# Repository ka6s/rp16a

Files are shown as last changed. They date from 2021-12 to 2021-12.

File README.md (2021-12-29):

# rp16a
This is version 1.3 of the rp16a Red Pitaya Shield.  This is an enhancment over the rp_adapter in several ways.  The design adds 10db and 20db attenuation. It has interfaces for both Alex filtering and 4 bit bus control for OTHER external filters.  It provides control for a 3 antenna switch.   The design uses a single 12V supply and mounts the Red Pitaya underneath the shield. 

Also contained within this repository are the following:
sdr-transceiver-hpsdr.c - custom version of Pavel's code to use with this radio.  
cc - compiler command to compile the above.
RP_i2c_to_SPI_v2.tar.gz - PSoC Creator 4.4 tar ball for the on-board PSOC that provides antenna control and translation for Alex.

If you aren't going to use Alex -and only 1 antenna - then you don't need any of these files.

Steve KA6S

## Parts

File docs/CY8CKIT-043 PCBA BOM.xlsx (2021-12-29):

TITLE |  | CY8CKIT-043 PSoC 4 M-Series Prototyping Kit
PCA # |  | 121-60220-01 | REV 04
SCH # |  | 630-60252-01 | REV 04
DATE |  | 2015-06-24
Item | Qty | Reference | Value | Description | Manufacturer | Mfr Part Number | Sub Allowed | ROHS | UL Certified
1 | 1 | 600-60250-01 REV04 | - | PCB, 116.51 mm x 24.13 mm, High Tg, ENIG finish, 2 layer, Color = RED, Silk = WHITE | Cypress Semiconductor | 600-60250-01 | N/A | Yes | Yes
2 | 14 | C1,C4,C5,C6,C8,C11,C14,C18,C19,C20,C22,C29,C33,C34 | 0.1 uFd | CAP CER 0.1UF 10V 10% X5R 0402 | TDK Corporation | C1005X5R1A104K050BA | ASK | Yes | Yes
3 | 13 | C3,C15,C16,C17,C21,C23,C24,C25,C26,C27,C28,C31,C32 | 1.0 uFd | CAP CERAMIC 1.0UF 25V X5R 0603 10% | Taiyo Yuden | TMK107BJ105KA-T | ASK | Yes | Yes
4 | 1 | C9 | 18 pF | CAP CER 18PF 50V 1% NP0 0402 | Murata Electronics | GRM1555C1H180FA01D | ASK | Yes | Yes
5 | 1 | C10 | 2200 pFd | CAP CER 2200PF 50V 5% NP0 0805 | Murata | GRM2165C1H222JA01D | ASK | Yes | Yes
6 | 1 | C12 | 36 pF | CAP CER 36PF 50V 5% NP0 0402 | Murata Electronics | GRM1555C1H360JA01D | ASK | Yes | Yes
7 | 1 | C13 | 10000 pFd | CAP CER 10000PF 50V 5% NP0 0805 | Murata | GRM2195C1H103JA01D | ASK | Yes | Yes
8 | 1 | D1 | MBR0520L | DIODE SCHOTTKY 0.5A 20V SOD-123 | Fairchild Semiconductor | MBR0520L | ASK | Yes | Yes
9 | 1 | F1 | PTC Resettable Fuse | FUSE, PTC Resettable, 0.50A, 16V, 1210, SMD | Bel Fuse Inc | 0ZCH0050FF2G | ASK | Yes | Yes
10 | 1 | LED1 | User LED BLUE | LED, BLUE, CLEAR, 0805, SMD | Lite-On Inc | LTST-C170TBKT | ASK | Yes | Yes
11 | 1 | LED2 | Power LED Amber | LED 595NM AMB DIFF 0805 SMD | Avago Technologies | HSMA-C170 | ASK | Yes | Yes
12 | 1 | LED3 | Status LED Green | LED GREEN CLEAR 0805 SMD | Chicago Miniature | CMD17-21VGC/TR8 | ASK | Yes | Yes
13 | 3 | L1,L2,L3 | 330 OHM @ 100MHz | FILTER CHIP 330 OHM 1.5A 0603 | Murata Electronics | BLM18SG331TN1D | ASK | Yes | Yes
14 | 2 | R2,R3 | 15K | RES SMD 15K OHM 5% 1/10W 0402 | Panasonic - ECG | ERJ-2GEJ153X | ASK | Yes | Yes
15 | 2 | R4,R5 | 22E | RES SMD 22 OHM 1% 1/10W 0402 | Panasonic - ECG | ERJ-2RKF22R0X | ASK | Yes | Yes
16 | 2 | R6,R8 | 2.2K | RES 2.2K OHM 1/10W 5% 0603 SMD | Panasonic - ECG | ERJ-3GEYJ222V | ASK | Yes | Yes
17 | 2 | R7,R22 | ZERO | RES 0.0 OHM 1/8W 0805 SMD | Panasonic-ECG | ERJ-6GEY0R00V | ASK | Yes | Yes
18 | 1 | R9 | 560 ohm | RES 560 OHM 1/10W 5% 0603 SMD | Panasonic - ECG | ERJ-3GEYJ561V | ASK | Yes | Yes
19 | 2 | R10,R12 | 30K | RES SMD 30K OHM 5% 1/10W 0402 | Panasonic - ECG | ERJ-2GEJ303X | ASK | Yes | Yes
20 | 12 | R11,R13,R14,R16,R17,R18,R20,R21,R24,R26,R27,R28 | ZERO | RES 0.0 OHM 1/8W 0603 SMD | Panasonic-ECG | ERJ-3GEY0R00V | ASK | Yes | Yes
21 | 1 | R15 | 560 ohm | RES 560 OHM 1/8W 5% 0805 SMD | Panasonic - ECG | ERJ-6GEYJ561V | ASK | Yes | Yes
22 | 1 | R19 | 820 ohm | RES 820 OHM 1/8W 5% 0603 SMD | Panasonic - ECG | ERJ-3GEYJ821V | ASK | Yes | Yes
23 | 2 | SW1,SW3 | SW PUSHBUTTON | SWITCH TACTILE SPST-NO 0.05A 32V | C&K Components | KMR221GLFS | ASK | Yes | Yes
24 | 1 | U1 | PSoC 5LP | 68QFN PSoC 5LP chip for USB debug channel and USB-Serial interface | Cypress Semiconductor | CY8C5868LTI-LP039 | ASK | Yes | Yes
25 | 1 | U2 | PSoC 4200M | 68TQFP PSoC 4M | Cypress Semiconductor | CY8C4247AZI-M485 | ASK | Yes | Yes
26 | 1 | U3 | DUAL PMOS | MOSFET 2P-CH 20V 430MA SOT-563 | ON Semiconductor | NTZD3152PT1G | ASK | Yes | Yes
Label
27 | 1 | N/A | N/A | LBL, PCA Label, Vendor Code, Datecode, Serial Number 121-60220-01 Rev 04 (YYWWVVXXXXX) | Cypress Semiconductor |  | ASK | Yes | Yes
No load components
28 | 2 | C2,C30 | 0.1 uFd | CAP CER 0.1UF 10V 10% X5R 0402 | TDK Corporation | C1005X5R1A104K050BA | ASK | Yes | Yes
29 | 1 | C7 | 1.0 uFd | CAP CERAMIC 1.0UF 25V X5R 0603 10% | Taiyo Yuden | TMK107BJ105KA-T | ASK | Yes | Yes
30 | 1 | J4 | HDR 1x2 | CONN HEADR BRKWAY .100 02POS STR | TE Connectivity | 9-146280-0-02 | ASK | Yes | Yes
31 | 1 | J5 | 50MIL KEYED SMD | CONN HEADER 10 PIN 50MIL KEYED SMD | Samtec | FTSH-105-01-L-DV-K | ASK | Yes | Yes
32 | 1 | R1 | 4.7K | RES SMD 4.7K OHM 5% 1/10W 0402 | Panasonic - ECG | ERJ-2GEJ472X | ASK | Yes | Yes
33 | 1 | R25 | ZERO | RES 0.0 OHM 1/8W 0805 SMD | Panasonic - ECG | ERJ-6GEY0R00V | ASK | Yes | Yes
34 | 1 | R23 | 4.7K | RES 4.7K OHM 1/10W 5% 0603 SMD | Panasonic - ECG | ERJ-3GEYJ472V | ASK | Yes | Yes
35 | 1 | SW2 | SW PUSHBUTTON | SWITCH TACTILE SPST-NO 0.05A 32V | C&K Components | KMR221GLFS | ASK | Yes | Yes
36 | 1 | SW4 | DPDT SW | SWITCH SLIDE DPDT 200MA 12V | Copal Electronics | CL-SB-22B-02T | ASK | Yes | Yes
37 | 1 | TP5 | BLACK | TEST POINT 43 HOLE 65 PLATED BLACK | Keystone Electronics | 5001 | ASK | Yes | Yes
38 | 4 | TP1,TP2,TP3,TP4 | RED | TEST POINT 43 HOLE 65 PLATED RED | Keystone Electronics | 5000 | ASK | Yes | Yes
39 | 1 | U4 | EZ-BLE | EZ-BLE PRoC BLE Module, 10 mm X 10 mm X 1.8 mm | Cypress Semiconductor | CYBLE-022001-00 | ASK | Yes | Yes

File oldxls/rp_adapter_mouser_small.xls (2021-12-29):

Mouser Part number | Manufacturer | Mfg Part Number | Description | Location | Quantity | Price 1 | Cost/Unit/10 | Location | Price 1 | Min\Mult Order Qty | Quoted Part Number
81-GRM422X105K50L (http://www.mouser.com/ProductDetail/Murata-Electronics/GRM32RR71H105KA01L/) | Murata | GRM32RR71H105KA01L (http://www.mouser.com/ProductDetail/Murata-Electronics/GRM32RR71H105KA01L/) | 1uF | C53,C55,C57,C54,C40 | 7 | 0.32 | 0.17 |  | $0.17 | 1\1 | 81-GRM422X105K50L
81-GRM422R106K16L (http://www.mouser.com/ProductDetail/Murata-Electronics/GRM32DR61C106KA01L/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) | Murata | GRM32DR61C106KA01L (http://www.mouser.com/ProductDetail/Murata-Electronics/GRM32DR61C106KA01L/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) | 10uF | C30,C2,C47,C49,C48,C41,C37,C42,C43 | 10 | 0.32 | 0.185 |  | $0.255 | 1\1 | 81-GRM422R106K16L
80-C1206C104K5R (http://www.mouser.com/ProductDetail/Kemet/C1206C104K5RACTU/) | Kemet | C1206C104K5RACTU (http://www.mouser.com/ProductDetail/Kemet/C1206C104K5RACTU/) | 0.1uF | C44,C50,C35,C36,C34,C33,C39,C38,C45,C51,C46,C52,C31 | 15 | 0.1 | 0.042 |  | $0.042 | 1\1 | 80-C1206C104K5R
80-C1210C107M4PACTU (http://www.mouser.com/ProductDetail/Kemet/C1210C107M4PACTU/) | Kemet | C1210C107M4PACTU (http://www.mouser.com/ProductDetail/Kemet/C1210C107M4PACTU/) | 100uF | C55,C54,C53,C40,C57,C1 | 7 | 2.46 | 0.836 |  | $2.46 | 1\1 | 80-C1210C107M4PACTU
490-PJ-002BH | Cui | PJ-002BH | BARREL_JACK | CON1 | 1 | 1.16 | 1.25 |  | $1.16 | 1\1 | 490-PJ-002BH
576-0437005.WR (http://www.mouser.com/ProductDetail/Littelfuse/0437005WR/) | Littelfuse (http://www.mouser.com/littelfuse) | 0437005.WR (http://www.mouser.com/ProductDetail/Littelfuse/0437005WR/) | FUSE | F1 | 1 | 0.92 | 0.688 |  | $0.92 | 1\1 | 576-0437005.WR
532-529801B25G | Aavid Thermalloy | 529801B02500G | HEATSINK | HS3,HS2 | 2 | 1.47 | 1.39 |  | $1.47 | 1\1 | 532-529801B25G
710-618015231221 (http://www.mouser.com/ProductDetail/Wurth-Electronics/618015231221/?qs=sGAEpiMZZMt93J8DTi5DC553G%252bzlR8Bc) | Wurth | 618015231221 (http://www.mouser.com/ProductDetail/Wurth-Electronics/618015231221/?qs=sGAEpiMZZMt93J8DTi5DC553G%252bzlR8Bc) | DB15 | J1 | 1 | 3.21 | 3.06 |  | $3.21 | 1\1 | 710-618015231221
523-L717SDB25P1ACH3R | Amphenol | L717SDB25P1ACH3R (http://www.mouser.com/ProductDetail/Amphenol-Commercial-Products/L717SDB25P1ACH3R/) | DB25 | J2 | 1 | 2.38 | 2.28 |  | $2.38 | 1\1 | 523-L717SDB25P1ACH3R
712-CONSMA002 (http://www.mouser.com/ProductDetail/Linx-Technologies/CONSMA002/?qs=K5ta8V%252bWhtYroTuiMsq2AA%3D%3D) | Linx Tech | CONSMA002 (http://www.mouser.com/ProductDetail/Linx-Technologies/CONSMA002/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) | SMA | J4,J3,J5 | 3 | 3.31 | 3.03 |  | $3.31 | 1\1 | 712-CONSMA002
490-SJ1-3533N (http://www.mouser.com/ProductDetail/CUI/SJ1-3533N/) | Cui | SJ1-3533N | JACK_2P | J11,J10,J9,J8,J6 | 5 | 1.6 | 1.24 |  | $1.60 | 1\1 | 490-SJ1-3533N
653-G6J-2P-Y-DC12 (http://www.mouser.com/ProductDetail/Omron-Electronics/G6J-2P-Y-DC12/) | Omron | G6J-2P-Y-DC12 | RELAY_RF | K2,K1 | 2 | 4.29 | 4.03 |  | $4.29 | 1\1 | 653-G6J-2P-Y-DC12
81-NFZ32BW621HN10L | Murata | NFZ32BW621HN10L | FB | L5,L4,L6,L3,L7 | 6 | 0.41 | 0.269 |  | $0.269 | 1\1 | 81-NFZ32BW621HN10L
563-BC-32678 | Bud Industries | BC-32678 | CONN_02X13 | P2,P1 | 2 | 2 | 1.8 |  | $2.00 | 1\1 | 563-BC-32678
652-CR1206FX-75R0ELF (http://www.mouser.com/ProductDetail/Bourns/CR1206-FX-75R0ELF/) | Bourns | CR1206-FX-75R0ELF (http://www.mouser.com/ProductDetail/Bourns/CR1206-FX-75R0ELF/) | 75 | R13 | 5 | 0.1 | 0.042 |  | $0.10 | 1\1 | 652-CR1206FX-75R0ELF
667-ERJ-8RQF5R1V (http://www.mouser.com/ProductDetail/Panasonic/ERJ-8RQF5R1V/) | Panasonic | ERJ-8RQF5R1V (http://www.mouser.com/ProductDetail/Panasonic/ERJ-8RQF5R1V/) | 5R1 | R22,R21 | 5 | 0.56 | 0.22 |  | $0.56 | 1\1 | 667-ERJ-8RQF5R1V
71-CP00102R200JE663 | Vishay | CP00102R200JE663 | 2R2 | R24,R23 | 2 | 0.67 | 0.495 |  | $4.29 | 1\1 | 653-G6J-2P-Y-DC12
667-ERJ-8GEYJ472V (http://www.mouser.com/ProductDetail/Panasonic/ERJ-8GEYJ472V/) | Panasonic | ERJ-8GEYJ472V (http://www.mouser.com/ProductDetail/Panasonic/ERJ-8GEYJ472V/) | 4.7K | R27,R25,R26 | 5 | 0.1 |  |  | $0.022 | 1\1 | 667-ERJ-8GEYJ472V
512-KA278R12CTU (http://www.mouser.com/ProductDetail/Fairchild-Semiconductor/KA278R12CTU/) | Fairchild | KA278R12CTU (http://www.mouser.com/ProductDetail/Fairchild-Semiconductor/KA278R12CTU/) | KA278R12 | U10 | 1 | 0.99 | 0.848 |  | $0.99 | 1\1 | 512-KA278R12CTU
879-1336G1 (http://www.mouser.com/ProductDetail/Anderson-Power-Products/1336G1/?qs=sGAEpiMZZMuP%2FQeRSdvksJ%2FdnJShAKpx) | Anderson Power Products (http://www.mouser.com/Anderson-Power-Products/) | 1336G1 (http://www.mouser.com/ProductDetail/Anderson-Power-Products/1336G1/?qs=sGAEpiMZZMuP%2FQeRSdvksJ%2FdnJShAKpx) | PwrPole | U11 | 2 | 0.54 |  |  | $0.54 | 1\1 | 879-1336G1
879-1327G6 (http://www.mouser.com/ProductDetail/Anderson-Power-Products/1327G6/?qs=sGAEpiMZZMuP%2FQeRSdvksFwvD3ebCz4Y) | Anderson Power Products (http://www.mouser.com/Anderson-Power-Products/) | 1327G6 | 1327G6 (http://www.mouser.com/ProductDetail/Anderson-Power-Products/1327G6/?qs=sGAEpiMZZMuP%2FQeRSdvksFwvD3ebCz4Y) | U12,U11 | 2 |  |  |  | $0.48 | 1\1 | 879-1327G6
879-1327 (http://www.mouser.com/ProductDetail/Anderson-Power-Products/1327/?qs=sGAEpiMZZMuP%2FQeRSdvksHAvir4742Xo) | Anderson Power Products (http://www.mouser.com/Anderson-Power-Products/) | 1327 | PwrPole Shroud Red | U12,U11 | 2 |  |  |  | $0.50 | 1\1 | 879-1327
879-1335G1 (http://www.mouser.com/ProductDetail/Anderson-Power-Products/1335G1/?qs=sGAEpiMZZMuP%2FQeRSdvksBiQHnjEfqU3) | Anderson Power Products (http://www.mouser.com/Anderson-Power-Products/) | 1335G1 (http://www.mouser.com/ProductDetail/Anderson-Power-Products/1335G1/?qs=sGAEpiMZZMuP%2FQeRSdvksBiQHnjEfqU3) | Powe Pole Vert | U12 | 2 |  |  |  |  | 1\1 | 879-1335G1
700-MAX2611EUS+T (http://www.mouser.com/ProductDetail/Maxim-Integrated/MAX2611EUS+T/?qs=GxOUx7aO6nzhsdyrBwYTYA%3D%3D) | Maxim | MAX2611EUS+T | MAX2611 | U6 | 1 | 1.78 | 1.68 |  | $1.78 | 1\1 | 700-MAX2611EUS+T
595-OPA2674ID (http://www.mouser.com/ProductDetail/Texas-Instruments/OPA2674ID/?qs=7nS3%252bbEUL6ta%252bQbwv%2FJuYg%3D%3D) | TI | OPA2674ID (http://www.mouser.com/ProductDetail/Texas-Instruments/OPA2674ID/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) | OPA26741C | U7 | 1 | 4.14 | 3.72 |  | $4.14 | 1\1 | 595-OPA2674ID
512-KA278R05CTU | Fairchild | KA278R05CTU | KA278R05 | U8,U9 | 2 | 0.98 | 0.836 |  | $0.98 | 1\1 | 512-KA278R05CTU
571-5-1634506-1 | TE Connectivity (http://www.mouser.com/TE-Connectivity/) | 5-1634506-1 | BNC_VERTICAL | P8,P10,P14,P9,P15 | 5 | 1.36
511-ULN2001A | STMicro | ULN2001A | ULN2004A | U1,U2 | 2 | 0.47
279-CBT50J100R (http://www.mouser.com/ProductDetail/TE-Connectivity-Neohm/CBT50J100R/) | TE Connectivity | CBT25J100R (http://www.mouser.com/ProductDetail/TE-Connectivity-Neohm/CBT25J100R/) | 100 | R15,R16 | 2
603-MFR-25FRF521K (http://www.mouser.com/ProductDetail/Yageo/MFR-25FRF52-1K/) | Yageo | MFR-25FRF52-1K (http://www.mouser.com/ProductDetail/Yageo/MFR-25FRF52-1K/) | 1K | R18,R17,R19,R20 | 4
 |  |  | CONN_01X29 | P3,P4 | 2

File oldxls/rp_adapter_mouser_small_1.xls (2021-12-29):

Mouser Part number | Manufacturer | Mfg Part Number | Description | Location | Quantity | Price 1 | Cost/Unit/10 | Location | Price 1 | Min\Mult Order Qty | Quoted Part Number
81-GRM422X105K50L (http://www.mouser.com/ProductDetail/Murata-Electronics/GRM32RR71H105KA01L/) | Murata | GRM32RR71H105KA01L (http://www.mouser.com/ProductDetail/Murata-Electronics/GRM32RR71H105KA01L/) | 1uF | C56,C32,C25,C24,C9,C7,C5,C3,C2,C1 | 20 | 0.32 | 0.17 |  | $0.17 | 1\1 | 81-GRM422X105K50L
80-C1206C101K5R (http://www.mouser.com/ProductDetail/Kemet/C1206C101K5RACTU/) | Kemet | C1206C101K5RACTU (http://www.mouser.com/ProductDetail/Kemet/C1206C101K5RACTU/) | 100pF | C23,C22,C21,C20,C18,C17,C16,C15,C14,C13,C12,C19 | 15 | 0.1 | 0.042 |  | $0.185 | 1\1 | 80-C1206C101K5R
81-GRM422R106K16L (http://www.mouser.com/ProductDetail/Murata-Electronics/GRM32DR61C106KA01L/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) | Murata | GRM32DR61C106KA01L (http://www.mouser.com/ProductDetail/Murata-Electronics/GRM32DR61C106KA01L/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) | 10uF | C49,C48,C47,C43,C42,C41,C37,C30 | 10 | 0.32 | 0.185 |  | $0.255 | 1\1 | 81-GRM422R106K16L
80-C1206C104K5R (http://www.mouser.com/ProductDetail/Kemet/C1206C104K5RACTU/) | Kemet | C1206C104K5RACTU (http://www.mouser.com/ProductDetail/Kemet/C1206C104K5RACTU/) | 0.1uF | C52,C51,C50,C46,C45,C44,C39,C38,C36,C35,C34,C33,C31,C29,C28,C27,C26,C11,C10,C8,C6,C4 | 25 | 0.1 | 0.042 |  | $0.042 | 1\1 | 80-C1206C104K5R
80-C1210C107M4PACTU (http://www.mouser.com/ProductDetail/Kemet/C1210C107M4PACTU/) | Kemet | C1210C107M4PACTU (http://www.mouser.com/ProductDetail/Kemet/C1210C107M4PACTU/) | 100uF | C55,C54,C53,C40,C57 (1210) | 8 | 2.46 | 0.836 |  | $2.46 | 1\1 | 80-C1210C107M4PACTU
490-PJ-002BH | Cui | PJ-002BH | BARREL_JACK | CON1 | 1 | 1.16 | 1.25 |  | $1.16 | 1\1 | 490-PJ-002BH
576-0437005.WR (http://www.mouser.com/ProductDetail/Littelfuse/0437005WR/) | Littelfuse (http://www.mouser.com/littelfuse) | 0437005.WR (http://www.mouser.com/ProductDetail/Littelfuse/0437005WR/) | FUSE | F1 | 1 | 0.92 | 0.688 |  | $0.92 | 1\1 | 576-0437005.WR
532-529801B25G | Aavid Thermalloy | 529801B02500G | HEATSINK | HS3,HS2 | 2 | 1.47 | 1.39 |  | $1.47 | 1\1 | 532-529801B25G
710-618015231221 (http://www.mouser.com/ProductDetail/Wurth-Electronics/618015231221/?qs=sGAEpiMZZMt93J8DTi5DC553G%252bzlR8Bc) | Wurth | 618015231221 (http://www.mouser.com/ProductDetail/Wurth-Electronics/618015231221/?qs=sGAEpiMZZMt93J8DTi5DC553G%252bzlR8Bc) | DB15 | J1 | 1 | 3.21 | 3.06 |  | $3.21 | 1\1 | 710-618015231221
523-L717SDB25P1ACH3R | Amphenol | L717SDB25P1ACH3R (http://www.mouser.com/ProductDetail/Amphenol-Commercial-Products/L717SDB25P1ACH3R/) | DB25 | J2 | 1 | 2.38 | 2.28 |  | $2.38 | 1\1 | 523-L717SDB25P1ACH3R
712-CONSMA002 (http://www.mouser.com/ProductDetail/Linx-Technologies/CONSMA002/?qs=K5ta8V%252bWhtYroTuiMsq2AA%3D%3D) | Linx Tech | CONSMA002 (http://www.mouser.com/ProductDetail/Linx-Technologies/CONSMA002/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) | SMA | J5,J4,J3 | 3 | 3.31 | 3.03 |  | $3.31 | 1\1 | 712-CONSMA002
490-SJ1-3533N (http://www.mouser.com/ProductDetail/CUI/SJ1-3533N/) | Cui | SJ1-3533N | JACK_2P | J11,J10,J9,J8,J6 | 5 | 1.6 | 1.24 |  | $1.60 | 1\1 | 490-SJ1-3533N
653-G6J-2P-Y-DC12 (http://www.mouser.com/ProductDetail/Omron-Electronics/G6J-2P-Y-DC12/) | Omron | G6J-2P-Y-DC12 | RELAY_RF | K2,K1 | 2 | 4.29 | 4.03 |  | $4.29 | 1\1 | 653-G6J-2P-Y-DC12
81-LQH31MNR47K03L (http://www.mouser.com/ProductDetail/Murata-Electronics/LQH31MNR47K03L/) | Murata | LQH31MNR47K03L (http://www.mouser.com/ProductDetail/Murata-Electronics/LQH31MNR47K03L/) | 0.47uH | L2,L1 | 2 | 0.44 | 0.335 |  | $0.44 | 1\1 | 81-LQM31PNR47MC0L
81-NFZ32BW621HN10L | Murata | NFZ32BW621HN10L | FB | L6,L5,L4,L3,L7 | 6 | 0.41 | 0.269 |  | $0.269 | 1\1 | 81-NFZ32BW621HN10L
645-598-8270-107F (http://www.mouser.com/ProductDetail/Dialight/598-8270-107F/) | Dialight | 598-8270-107F (http://www.mouser.com/ProductDetail/Dialight/598-8270-107F/) | LED | LED_D1,LED_C1,LED_B1,LED_A1 | 4 | 0.46 |  |  | $0.46 | 1\1 | 645-598-8270-107F
563-BC-32678 | Bud Industries | BC-32678 | CONN_02X13 | P2,P1 | 2 | 2 | 1.8 |  | $2.00 | 1\1 | 563-BC-32678
571-5227677-1 | TE Connectivity | 5227677-1 | BNC | P15,P14,P11,P10,P9,P8 | 6 | 3.3 | 3.17 |  | $3.30 | 1\1 | 571-5227677-1
652-CR1206FX-75R0ELF (http://www.mouser.com/ProductDetail/Bourns/CR1206-FX-75R0ELF/) | Bourns | CR1206-FX-75R0ELF (http://www.mouser.com/ProductDetail/Bourns/CR1206-FX-75R0ELF/) | 75 | R13 | 5 | 0.1 | 0.042 |  | $0.10 | 1\1 | 652-CR1206FX-75R0ELF
667-ERJ-8GEYJ101V (http://www.mouser.com/ProductDetail/Panasonic/ERJ-8GEYJ101V/) | Bourns | ERJ-8GEYJ101V (http://www.mouser.com/ProductDetail/Panasonic/ERJ-8GEYJ101V/) | 100 | R16,R15 | 5 | 0.1 | 0.022 |  | $0.10 | 1\1 | 667-ERJ-8GEYJ101V
652-CR1206-JW-102ELF (http://www.mouser.com/ProductDetail/Bourns/CR1206-JW-102ELF/) | Bourns | CR1206-JW-102ELF (http://www.mouser.com/ProductDetail/Bourns/CR1206-JW-102ELF/) | 1K | R20,R19,R18,R17 | 5 | 0.1 | 0.039 |  | $0.038 | 1\1 | 652-CR1206-JW-102ELF
667-ERJ-8RQF5R1V (http://www.mouser.com/ProductDetail/Panasonic/ERJ-8RQF5R1V/) | Panasonic | ERJ-8RQF5R1V (http://www.mouser.com/ProductDetail/Panasonic/ERJ-8RQF5R1V/) | 5R1 | R22,R21 | 5 | 0.56 | 0.22 |  | $0.56 | 1\1 | 667-ERJ-8RQF5R1V
71-CP00102R200JE663 | Vishay | CP00102R200JE663 | 2R2 | R24,R23 | 2 | 0.67 | 0.495 |  | $4.29 | 1\1 | 653-G6J-2P-Y-DC12
667-ERJ-8GEYJ472V (http://www.mouser.com/ProductDetail/Panasonic/ERJ-8GEYJ472V/) | Panasonic | ERJ-8GEYJ472V (http://www.mouser.com/ProductDetail/Panasonic/ERJ-8GEYJ472V/) | 4.7K | R26,R25,R5,R4,R3,R2,R1,R27 | 10 | 0.1 |  |  | $0.022 | 1\1 | 667-ERJ-8GEYJ472V
791-WR12X000PTL | Waisun | WR12X000 PTL | 0 | R12,R11,R10,R9,R8,R7,R6 | 10 | 0.11 |  |  | $0.11 | 1\1 | 791-WR12X000PTL
653-B3S-1000 (http://www.mouser.com/ProductDetail/Omron-Electronics/B3S-1000/) | Omron | B3S-1000 (http://www.mouser.com/ProductDetail/Omron-Electronics/B3S-1000/) | SW_PUSH | SW1 | 1 | 0.61 |  |  | $0.61 | 1\1 | 653-B3S-1000
727-CY8C4247AXI-M485 (http://www.mouser.com/ProductDetail/Cypress-Semiconductor/CY8C4247AXI-M485/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) | Cypress | CY8C4247AXI-M485 | CY8C4247AXIM | U1 | 1 | 6.37 | 5.51 |  | $6.37 | 1\1 | 727-CY8C4247AXI-M485
512-KA278R12CTU (http://www.mouser.com/ProductDetail/Fairchild-Semiconductor/KA278R12CTU/) | Fairchild | KA278R12CTU (http://www.mouser.com/ProductDetail/Fairchild-Semiconductor/KA278R12CTU/) | KA278R12 | U10 | 1 | 0.99 | 0.848 |  | $0.99 | 1\1 | 512-KA278R12CTU
879-1336G1 (http://www.mouser.com/ProductDetail/Anderson-Power-Products/1336G1/?qs=sGAEpiMZZMuP%2FQeRSdvksJ%2FdnJShAKpx) | Anderson Power Products (http://www.mouser.com/Anderson-Power-Products/) | 1336G1 (http://www.mouser.com/ProductDetail/Anderson-Power-Products/1336G1/?qs=sGAEpiMZZMuP%2FQeRSdvksJ%2FdnJShAKpx) | PwrPole | U11 | 2 | 0.54 |  |  | $0.54 | 1\1 | 879-1336G1
879-1327G6 (http://www.mouser.com/ProductDetail/Anderson-Power-Products/1327G6/?qs=sGAEpiMZZMuP%2FQeRSdvksFwvD3ebCz4Y) | Anderson Power Products (http://www.mouser.com/Anderson-Power-Products/) | 1327G6 | 1327G6 (http://www.mouser.com/ProductDetail/Anderson-Power-Products/1327G6/?qs=sGAEpiMZZMuP%2FQeRSdvksFwvD3ebCz4Y) | U12,U11 | 2 |  |  |  | $0.48 | 1\1 | 879-1327G6
879-1327 (http://www.mouser.com/ProductDetail/Anderson-Power-Products/1327/?qs=sGAEpiMZZMuP%2FQeRSdvksHAvir4742Xo) | Anderson Power Products (http://www.mouser.com/Anderson-Power-Products/) | 1327 | PwrPole Shroud Red | U12,U11 | 2 |  |  |  | $0.50 | 1\1 | 879-1327
879-1335G1 (http://www.mouser.com/ProductDetail/Anderson-Power-Products/1335G1/?qs=sGAEpiMZZMuP%2FQeRSdvksBiQHnjEfqU3) | Anderson Power Products (http://www.mouser.com/Anderson-Power-Products/) | 1335G1 (http://www.mouser.com/ProductDetail/Anderson-Power-Products/1335G1/?qs=sGAEpiMZZMuP%2FQeRSdvksBiQHnjEfqU3) | Powe Pole Vert | U12 | 2 |  |  |  |  | 1\1 | 879-1335G1
595-CD4504BPWR (http://www.mouser.com/ProductDetail/Texas-Instruments/CD4504BPWR/?qs=LSR%252bNeaw%2FwDSi1l0SFbsAw%3D%3D) | TI | CD4504BPWR (http://www.mouser.com/ProductDetail/Texas-Instruments/CD4504BPWR/?qs=sGAEpiMZZMt7FrWooXVB1wQa44IR8MfB) | 4504 | U2,U3,U4 | 3 | 0.44 | 0.368 |  | $0.44 | 1\1 | 595-CD4504BPWR
595-ULN2003ADR | ULN2003ADR (http://www.mouser.com/ProductDetail/Texas-Instruments/ULN2003ADR/?qs=D5pVkbrsqqI8WxXD0eSvDA%3D%3D) | ULN2003ADR (http://www.mouser.com/ProductDetail/Texas-Instruments/ULN2003ADR/?qs=sGAEpiMZZMtYFXwiBRPs04XApsoE6l9l) | ULN2003 | U5 | 1 | 0.52 | 0.433 |  | $0.52 | 1\1 | 595-ULN2003ADR
700-MAX2611EUS+T (http://www.mouser.com/ProductDetail/Maxim-Integrated/MAX2611EUS+T/?qs=GxOUx7aO6nzhsdyrBwYTYA%3D%3D) | Maxim | MAX2611EUS+T | MAX2611 | U6 | 1 | 1.78 | 1.68 |  | $1.78 | 1\1 | 700-MAX2611EUS+T
595-OPA2674ID (http://www.mouser.com/ProductDetail/Texas-Instruments/OPA2674ID/?qs=7nS3%252bbEUL6ta%252bQbwv%2FJuYg%3D%3D) | TI | OPA2674ID (http://www.mouser.com/ProductDetail/Texas-Instruments/OPA2674ID/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) | OPA26741C | U7 | 1 | 4.14 | 3.72 |  | $4.14 | 1\1 | 595-OPA2674ID
512-KA278R05CTU | Fairchild | KA278R05CTU | KA278R05 | U9,U8 | 2 | 0.98 | 0.836 |  | $0.98 | 1\1 | 512-KA278R05CTU

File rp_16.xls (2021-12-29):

Reference | Quantity | Value | Mouser Part number
U6 | 2 | MAX2611 | 700-MAX2611EUS+T (https://www.mouser.com/ProductDetail/700-MAX2611EUS%2BT)
L4;L5;L1;L7;L2 | 5 | FB | 810-MPZ2012S101AT000
P14;J4;P15;J5 | 4 | SMA | 712-CONSMA020.062-G
U7 | 2 | OPA26741C | 595-OPA2674ID (https://www.mouser.com/ProductDetail/595-OPA2674ID)
C37 | 1 | 10uF | 963-TMK212BC6106KG-T (https://www.mouser.com/ProductDetail/963-TMK212BC6106KG-T)
J2;J3 | 2 | Conn_Coaxial | 502-3517PCX
CODEC1 | 1 | Conn_01x11 | 932-MIKROE-506
U1 | 1 | ULN2003 | 511-ULN2003A
P1;P2 | 2 | CONN_02X13 | 649-68683-313LF (https://www.mouser.com/ProductDetail/649-68683-313LF)
D2;D1 | 2 | ZENER | 771-NZX3V0C-133 (https://www.mouser.com/ProductDetail/771-NZX3V0C-133)
U2 | 1 | CY8CKIT-063-BLE | 727-CY8CPROTO-063BLE
J1 | 1 | Mini ATX Conn | 68683-310LF (https://www.mouser.com/ProductDetail/Amphenol-FCI/68683-310LF?qs=iIDwN1lGivTwLhV9P%2FXNfQ%3D%3D)
J8 | 1 | Jack_3.5mm_CUI_SJ1-3533NG_Horizontal | STX-3150-3N-1 (https://www.mouser.com/ProductDetail/Kycon/STX-3150-3N-1?qs=0lSvoLzn4L%252BTY%2FtkqS6zXQ%3D%3D)

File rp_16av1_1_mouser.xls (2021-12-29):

Reference | Quantity | Identifier | Package | Value | Mouser Part Number
U6 | 1 |  |  | MAX2611 | 700-MAX2611EUS+T (https://www.mouser.com/ProductDetail/700-MAX2611EUS%2BT)
L4;L5;L1;L7;L2;L3 | 6 |  |  | FB | 70-ILBB0805ER101V (https://www.mouser.com/ProductDetail/70-ILBB0805ER101V)
P14;J4;P15;J5 | 4 |  |  | SMA | 712-CONSMA020.062-G (https://www.mouser.com/ProductDetail/712-CONSMA020.062-G)
T3 | 1 |  |  | ADT1-1 | 139-ADT1-1
U7 | 1 |  |  | OPA26741C | 595-OPA2674ID (https://www.mouser.com/ProductDetail/595-OPA2674ID)
T2 | 1 |  |  | ADT1.5-1 | 139-ADT1.5-1
C37;C14;C15 | 3 |  |  | 10uF | 581-TCJA106M025R150E
T1 | 1 |  |  | TC4-LT | 139-TC4-1T
U4 | 1 |  |  | LD1085 | 511-LD1085V50
J2;J3 | 2 |  |  | Conn_Coaxial | 502-3517PCX (https://www.mouser.com/ProductDetail/502-3517PCX)
CODEC1 | 1 |  |  | Conn_01x11 | 932-MIKROE-506 (https://www.mouser.com/ProductDetail/932-MIKROE-506)
J8 | 1 |  |  | AudioJack2_Ground | 806-STX-3150-3N-1 (https://www.mouser.com/ProductDetail/806-STX-3150-3N-1)
U1 | 1 |  |  | ULN2003 | 511-ULN2003A (https://www.mouser.com/ProductDetail/511-ULN2003A)
P2;P1 | 2 |  |  | CONN_02X13 | 649-68683-313LF
D2;D1 | 2 |  |  | ZENER | 771-NZX3V0C-133 (https://www.mouser.com/ProductDetail/771-NZX3V0C-133)
J9 | 1 |  |  | Conn_02x05_Odd_Even
U2 | 1 |  |  | CY8C4127AXI-S443 | 727-CY8C4127AXI-S443 (https://www.mouser.com/ProductDetail/727-CY8C4127AXI-S443)

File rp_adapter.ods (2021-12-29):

Reference | Quantity | Value
C36;C35;C34;C38;C31;C3 | 6 | 0.1uF
U6 | 1 | MAX2611
L4;L5;L1;L7;L2 | 5 | FB
R13 | 1 | 75
P14;J4;P15;J5 | 4 | SMA
T3 | 1 | ADT1-1
R15;R16 | 2 | 100
U7 | 1 | OPA26741C
R17;R20;R19;R18;R2;R1 | 6 | 1K
T2 | 1 | ADT1.5-1
C37 | 1 | 10uF
T1 | 1 | TC4-LT
R22;R21 | 2 | 4R99
J1 | 1 | Conn_02x10_Top_Bottom
C2 | 1 | 0.001uF
C1 | 1 | 0.1 uF
C56;C4 | 2 | 1uF
R25;R26;R27 | 3 | 4.7K
J2;J3 | 2 | Conn_Coaxial
CODEC1 | 1 | Conn_01x11
U1 | 1 | ULN2003
J8 | 1 | AudioJack2_Ground
J6;J7 | 2 | Conn_01x02
P1;P2 | 2 | CONN_02X13
D2;D1 | 2 | ZENER
J9 | 1 | Conn_02x05_Odd_Even
U2 | 1 | CY8CKIT-062-BLE
R4;R3;R5 | 3 | 10K

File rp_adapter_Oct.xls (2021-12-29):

Reference | Quantity | Value | Mouser Part Number | Mouser Part NUmber | Mousr Part Number
U6 | 3 | MAX2611 | 700-MAX2611EUS+T
L4;L5;L1;L7;L2;L3 | 10 | FB | 70-ILBB0805ER101V (https://www.mouser.com/ProductDetail/70-ILBB0805ER101V)
T3 | 1 | ADT1-1 | 139-ADT1-1
J4;P15;J5 | 4 | SMA | 712-CONSMA001-C-G
K3;K1;K2 | 3 | RELAY_RF | 653-G6J-2P-Y-DC12
U7 | 1 | OPA26741D | 595-OPA2674I-14D
T2 | 1 | ADT1.5-1 | 139-ADT1.5-1
T1 | 1 | TC4-1T | 139-TC4-1TX
U4 | 1 | LM7805 | 511-LD1085V50
C14, C15 | 3 | 10uF | 80-C1206C106Z4VACTU
U8 | 1 | LM1085-5 | 511-LD1085V50
J2;J3 | 2 | Conn_Coaxial | 490-RCJ-027
J8 | 1 | AudioJack2_Ground | 523-ACJS-MV35-3
U5;U1 | 2 | ULN2003 | 595-ULN2003AIDE4
U2 | 1 | CY8C4127AXI-S443 | CY8C4126AZS-M443 (https://www.mouser.com/ProductDetail/Cypress-Semiconductor/CY8C4126AZS-M443)
P2;P1 | 2 | CONN_02X13 | 649-68683-313LF (https://www.mouser.com/ProductDetail/649-68683-313LF)
D2;D1 | 2 | ZENER | 771-NZX3V0C-133

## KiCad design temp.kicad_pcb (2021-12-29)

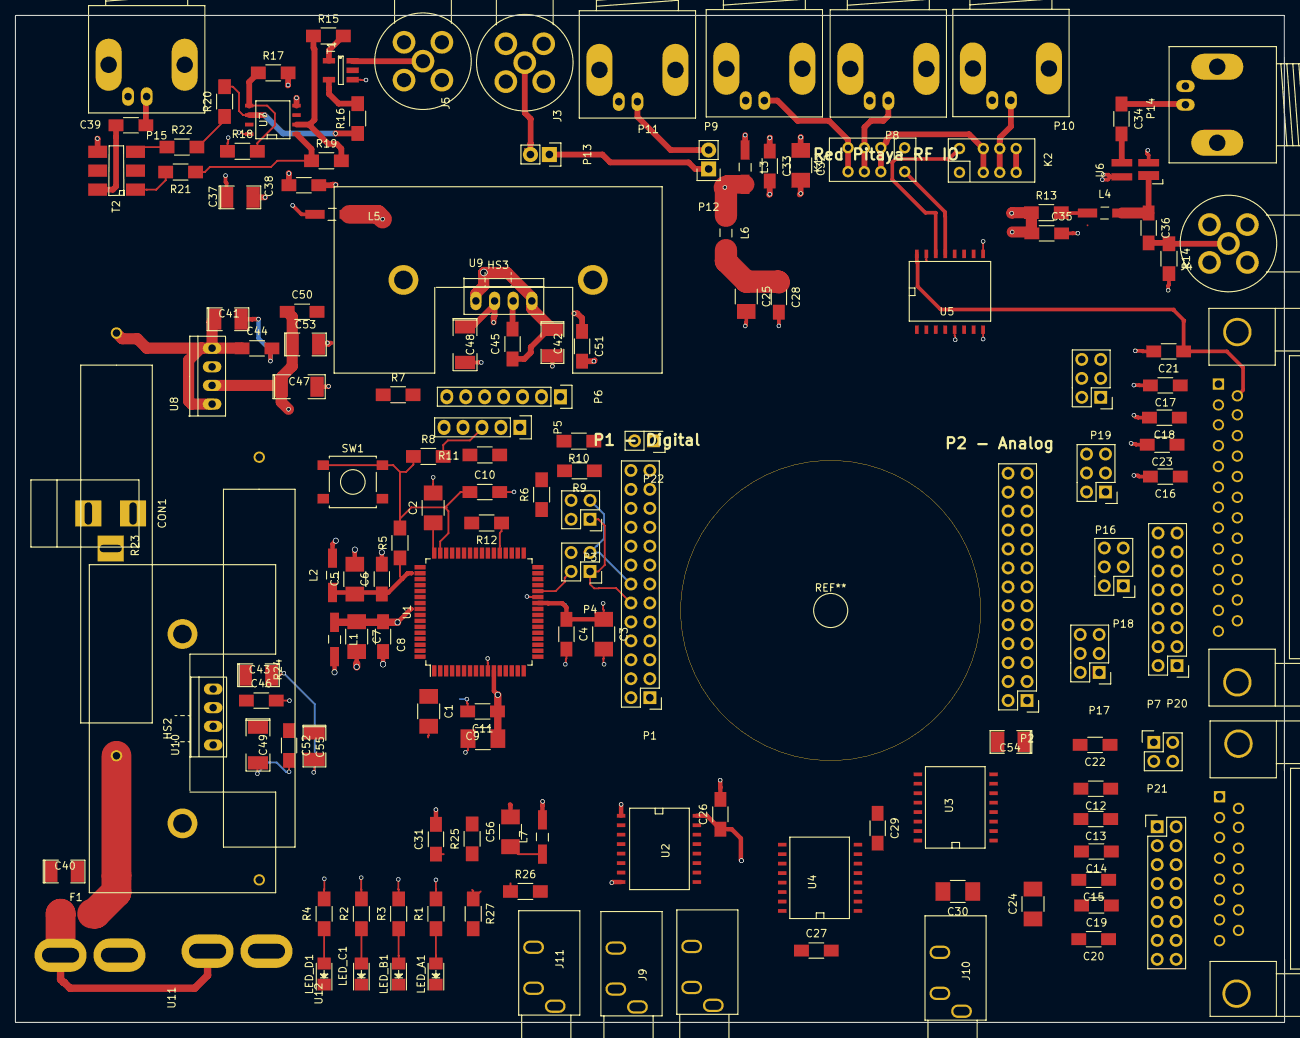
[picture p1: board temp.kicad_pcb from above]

Board: 4 copper layers, 170.2 x 135.1 mm, 146 parts (0 on the bottom side), 122 nets.

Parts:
C1, C2, C3, C5, C7, C9, C24, C25, C32, C56: 1uF; C_1210_HandSoldering
C4, C6, C8, C10, C11, C26, C27, C28, C29, C31, C33, C34, C35, C36, C38, C39, C44, C45, C46, C50, C51, C52: 0.1uF; C_1206_HandSoldering
C12, C13, C14, C15, C16, C17, C18, C19, C20, C21, C22, C23: 100pF; C_1206_HandSoldering
C30: 10uF; C_1210_HandSoldering
C37, C41, C42, C43: 10uF; SMD-1210_Pol
C40, C53, C54, C55: 100uF; SMD-1210_Pol
C47, C48, C49: 10uF; SMD-2010_Pol
CON1: BARREL_JACK
F1: FUSE; Fuse_SMD1206_HandSoldering
HS2, HS3: HEATSINK; Heatsink-TO220
J1: DB15; DB15FC
J2: DB25; DB25FC
J3, J4, J5: SMA; SMA_F_RA
J8, J9, J10, J11: JACK_2P; RA_3p5_audio_jack
K1, K2: RELAY_RF; RF_RELAY
L1, L2: 0.47uH; Choke_SMD_1206_Handsoldering
L3, L4, L5, L6, L7: FB; Choke_SMD_1206_Handsoldering
LED_A1: LED; LED_1206
LED_B1: LED; LED_1206
LED_C1: LED; LED_1206
LED_D1: LED; LED_1206
P1, P2: CONN_02X13; Pin_Header_Straight_2x13
P3, P4, P7: CONN_02X02; Pin_Header_Straight_2x02
P5: CONN_01X05; Pin_Header_Straight_1x05
P6: CONN_01X07; Pin_Header_Straight_1x07
P8, P9, P10, P11, P14, P15: BNC; BNC_Socket_TYCO-AMP_LargePads
P12, P13: CONN_01X02; Pin_Header_Straight_1x02
P16, P17, P18, P19: CONN_02X03; Pin_Header_Straight_2x03
P20, P21: CONN_02X08; Pin_Header_Straight_2x08
P22: CONN_02X01; Pin_Header_Straight_2x01
R1, R2, R3, R4, R5, R25, R26, R27: 4.7K; R_1206_HandSoldering
R6, R7, R8, R9, R10, R11, R12: 0; R_1206_HandSoldering
R13: 75; R_1206_HandSoldering
R14: 50; R_1206_HandSoldering
R15, R16: 100; R_1206_HandSoldering
R17, R18, R19, R20: 1K; R_1206_HandSoldering
R21, R22: 4R99; R_1206_HandSoldering
R23, R24: 2R2; RES_10W
SW1: SW_PUSH; SW_SPST_B3S-1000
T1: TC4-LT; TC4-1T
T2: ADT1.5-1
U1: CY8C4247AXIM; LQFP-64_14x14mm_Pitch0.8mm
U2, U3, U4: 4504; SO-16-W
U5: ULN2003; SO-16-W
U6: MAX2611; SOT-143_Handsoldering
U7: OPA26741C; SOIC-8-N
U8, U9: KA278R05; TO-220_4pin_vertical
U10: KA278R12; TO-220_4pin_vertical
U11, U12: PwrPole; RA_POWER_POLE

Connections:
+12V: C24.1, C25.1, C26.1, C27.1, C28.1, C29.1, J1.5, L6.2, U2.16, U3.16, U4.16
/extern_conn/AUDIO_IN: C30.1, P16.5, P17.5, P18.5, P19.5
/extern_conn/DASH: J8.1, P1.6, R26.2
/extern_conn/DOT: J11.1, P1.8, R25.2
/extern_conn/PTT_IN: J9.1, P1.4, R27.2
/filt_if/I2C_CLOCK: P1.14, P3.3, P4.3
/filt_if/I2C_DATA: P1.12, P3.1, P4.1
/filt_if/I2C_SCL: P6.3, R6.2
/filt_if/I2C_SDA: P6.5, R11.2
/filt_if/LPF0: U1.2, U2.14
/filt_if/LPF1: U1.3, U3.14
/filt_if/LPF2: U1.4, U2.5
/filt_if/LPF3: U1.5, U3.5
/filt_if/LPF4: U1.6, U2.3
/filt_if/LPF5: U1.7, U3.3
/filt_if/LPF6: U1.8, U4.3
/filt_if/LPF7: U1.9, U4.5
/filt_if/OUTA: LED_A1.1, U1.39, U2.9
/filt_if/OUTB: LED_B1.1, U1.40, U3.9
/filt_if/OUTC: LED_C1.1, U1.41, U2.11
/filt_if/OUTD: LED_D1.1, U1.42, U3.11
/filt_if/P4_VDDA: C7.1, C8.1, C9.1, C11.1, L1.1, U1.11, U1.56
/filt_if/P4_VDDD: C5.1, C6.1, L2.1, R5.1, U1.50
/filt_if/RESET: P5.3, R8.2
/filt_if/SAR_BYPASS: C1.1, U1.1
/filt_if/SWD_CLK: P5.4, R9.2
/filt_if/SWD_DATA: P5.5, R10.2
/filt_if/UART_RX: P6.6, R7.2
/filt_if/UART_TX: P6.7, R12.2
/filt_if/VCCD: C2.1, U1.48
/filt_if/XRES: C10.1, R5.2, R8.1, SW1.1, U1.47
/lna/5V_LNA: C35.1, C47.1, C50.1, C53.1, R13.1, U8.2
/lvlshift/12V_LVL_IN: C49.1, C52.1, C55.1, CON1.1, L3.2, L5.2, L6.1, U10.2
/lvlshift/ATTEN: P1.5, U2.7
/lvlshift/PTT: P1.3, U3.7
/lvlshift/PTT_OUT_RX: K2.8, U5.14
/lvlshift/PTT_OUT_TX: K1.8, U5.13
/lvlshift/SWR_F: P16.1, P17.1, P18.1, P19.1, P21.13
/lvlshift/lpf10o: J2.25, P20.1
/lvlshift/lpf15o: J2.24, P20.3
/lvlshift/lpf20o: J2.11, P20.5
/lvlshift/lpf40o: J2.23, P20.7
/lvlshift/lpf80o: J2.10, P20.9
/lvlshift/lpf160o: J2.22, P20.11
/lvlshift/lpf_0_12v: C12.1, P21.1, U2.15
/lvlshift/lpf_1_12V: C13.1, P21.3, U3.15
/lvlshift/lpf_2_12v: C14.1, P21.5, U2.4
/lvlshift/lpf_3_12v: C15.1, P21.7, U3.4
/lvlshift/lpf_4_12v: C19.1, P21.9, U2.2
/lvlshift/lpf_5_12v: C20.1, P21.11, U3.2
/lvlshift/lpf_10: J1.11, P20.2, P21.2
/lvlshift/lpf_15: J1.6, P20.4, P21.4
/lvlshift/lpf_20: J1.3, P20.6, P21.6
/lvlshift/lpf_40: J1.1, P20.8, P21.8
/lvlshift/lpf_80: J1.2, P20.10, P21.10
/lvlshift/lpf_160: J1.4, P20.12, P21.12
/lvlshift/swr_fd: J1.14, P20.14, P21.14
/lvlshift/swr_rv: J1.15, P20.16, P21.16
/lvlshift/swrf: J2.16, P20.13
/lvlshift/swrr: J2.15, P20.15
/mini_amp/AMP12V: C37.1, C38.1, L5.1, R18.1, U7.8
/ps/+13.8VA: C40.1, F1.1, U11.2, U12.2
/ps/+13.8VB: C43.1, C46.1, F1.2, R23.2, R24.2, U10.1, U10.4
/ps/+13.8VRA: C41.1, C44.1, R23.1, U8.1, U8.4
/ps/+13.8VRB: C42.1, C45.1, R24.1, U9.1, U9.4
/ps/RP_5V: C48.1, C51.1, C54.1, P2.1, U9.2
/rp_conn/SWR_R: P16.3, P17.3, P18.3, P19.3
/tr_switch/12V_Relay: C32.1, C33.1, K1.1, K2.1, L3.1
GND: C1.2, C2.2, C3.2, C4.2, C5.2, C6.2, C7.2, C8.2, C9.2, C10.2, C11.2, C12.2, C13.2, C14.2, C15.2, C16.2, C17.2, C18.2, C19.2, C20.2, C21.2, C22.2, C23.2, C24.2, C25.2, C26.2, C27.2, C28.2, C29.2, C31.2, C32.2, C33.2, C35.2, C37.2, C38.2, C40.2, C41.2, C42.2, C43.2, C44.2, C45.2, C46.2, C47.2, C48.2, C49.2, C50.2, C51.2, C52.2, C53.2, C54.2, C55.2, C56.2, CON1.2, CON1.3, J1.7, J1.8, J1.9, J3.2, J3.3, J3.4, J3.5, J4.2, J4.3, J4.4, J4.5, J5.2, J5.3, J5.4, J5.5, J8.2, J8.3, J9.2, J9.3, J10.2, J10.3, J11.2, J11.3, P1.25, P1.26, P2.21, P2.22, P2.25, P2.26, P5.2, P8.2, P9.2, P10.2, P11.2, P14.2, P15.2, R14.2, R17.2, SW1.2, T1.3, T2.4, U1.10, U1.17, U1.49, U1.57, U2.8, U3.8, U4.8, U5.5, U5.6, U5.7, U5.8, U5.9, U6.2, U6.4, U7.4, U8.3, U9.3, U10.3, U11.1, U12.1
unnamed: C16.1, J2.4, U2.10
unnamed: C17.1, J2.1, U3.10
unnamed: C18.1, J2.2, U2.12
unnamed: C21.1, J2.14, U5.16
unnamed: C22.1, P7.1, U5.15
unnamed: C23.1, J2.3, U3.12
unnamed: C30.2, J10.1
unnamed: C31.1, C56.1, L7.1, R25.1, R26.1, R27.1
unnamed: C34.1, P14.1
unnamed: C34.2, U6.3
unnamed: C36.1, L4.2, U6.1
unnamed: C36.2, J4.1, R14.1
unnamed: C39.1, P15.1
unnamed: C39.2, T2.6
unnamed: J1.10, P7.2, P7.4
unnamed: J3.1, P13.2
unnamed: J5.1, T1.1
unnamed: K1.2, K1.7, K2.2, K2.7
unnamed: K1.3, K1.6, P8.1
unnamed: K1.4, K1.5, P9.1
unnamed: K2.3, K2.6, P10.1
unnamed: K2.4, K2.5, P12.1, P13.1
unnamed: L4.1, R13.2
unnamed: LED_A1.2, R1.1
unnamed: LED_B1.2, R3.1
unnamed: LED_C1.2, R2.1
unnamed: LED_D1.2, R4.1
unnamed: P3.2, U1.52
unnamed: P3.4, U1.51
unnamed: P4.2, R11.1, U1.28
unnamed: P4.4, R6.1, U1.27
unnamed: P7.3, U3.6, U5.2, U5.3, U5.4
unnamed: P11.1, P12.2
unnamed: P2.13, P16.2, P16.4, P16.6
unnamed: P2.15, P17.2, P17.4, P17.6
unnamed: P2.16, P18.2, P18.4, P18.6
unnamed: P2.14, P19.2, P19.4, P19.6
unnamed: P5.1, P22.1
unnamed: R7.1, U1.38
unnamed: R9.1, U1.21
unnamed: R10.1, U1.20
unnamed: R12.1, U1.37
unnamed: R15.1, R19.2, U7.2
unnamed: R15.2, T1.6
unnamed: R16.1, R20.2, U7.6
unnamed: R16.2, T1.4
unnamed: R17.1, R18.2, U7.3, U7.5
unnamed: R19.1, R21.1, U7.1
unnamed: R20.1, R22.2, U7.7
unnamed: R21.2, T2.1
unnamed: R22.1, T2.3
unnamed: U2.6, U5.1
VCC: C3.1, C4.1, L1.2, L2.2, L7.2, P1.1, P1.2, P22.2, R1.2, R2.2, R3.2, R4.2, U1.26, U2.1, U2.13, U3.1, U3.13, U4.1, U4.13

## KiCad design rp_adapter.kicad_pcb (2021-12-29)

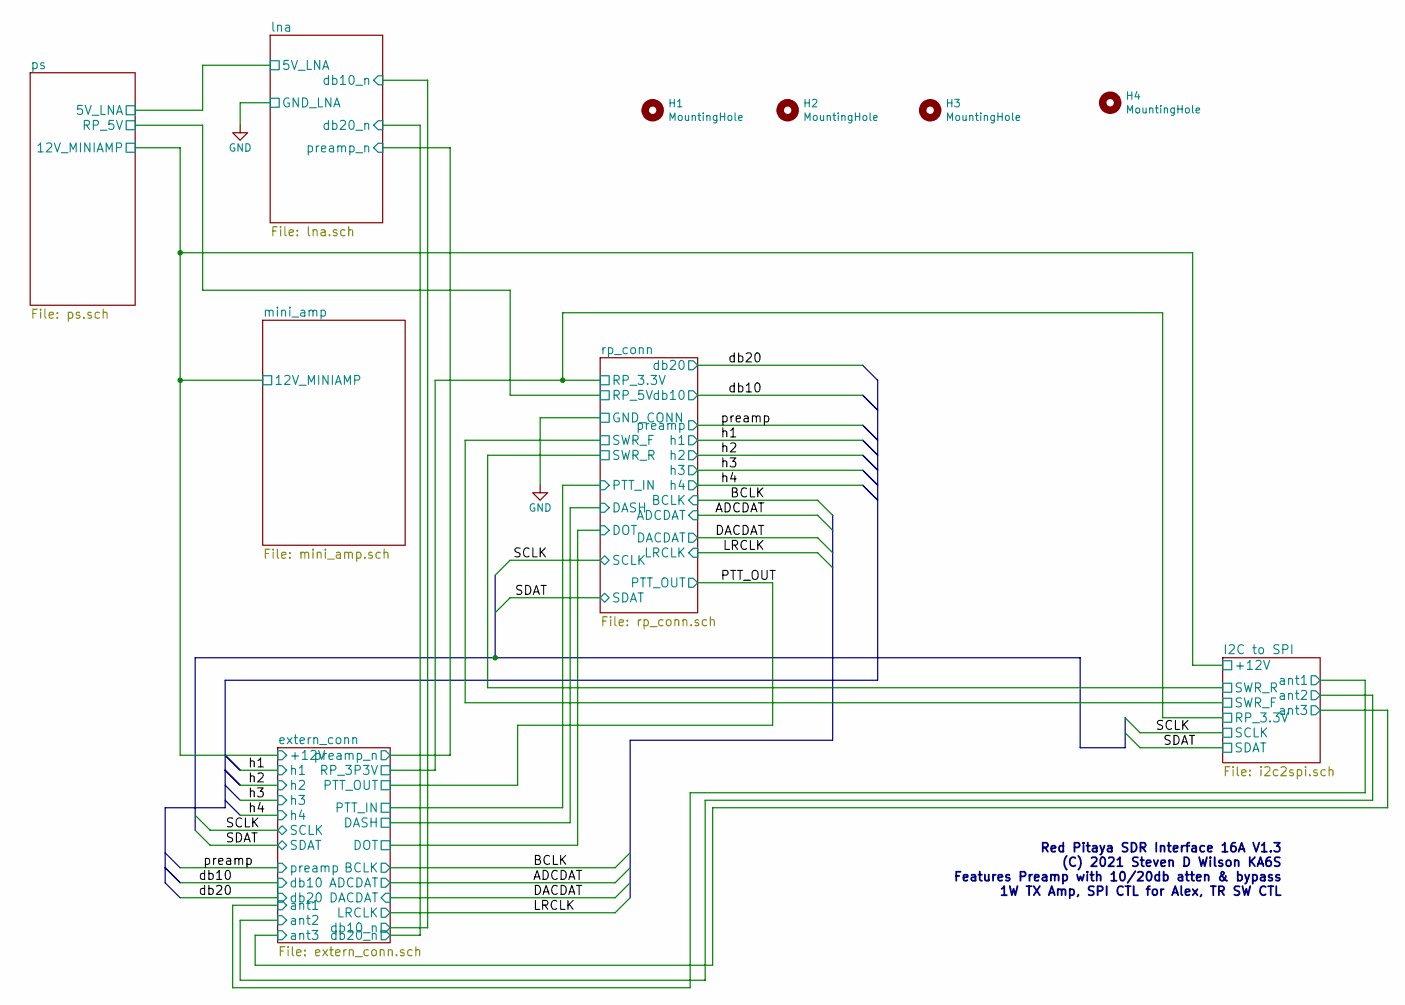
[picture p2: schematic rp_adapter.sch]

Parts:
H1, H2, H3, H4: MountingHole; MountingHole_4.3mm_M4

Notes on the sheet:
Red Pitaya SDR Interface 16A V1.3 (C) 2021 Steven D Wilson KA6S Features Preamp with 10/20db atten & bypass 1W TX Amp, SPI CTL for Alex, TR SW CTL

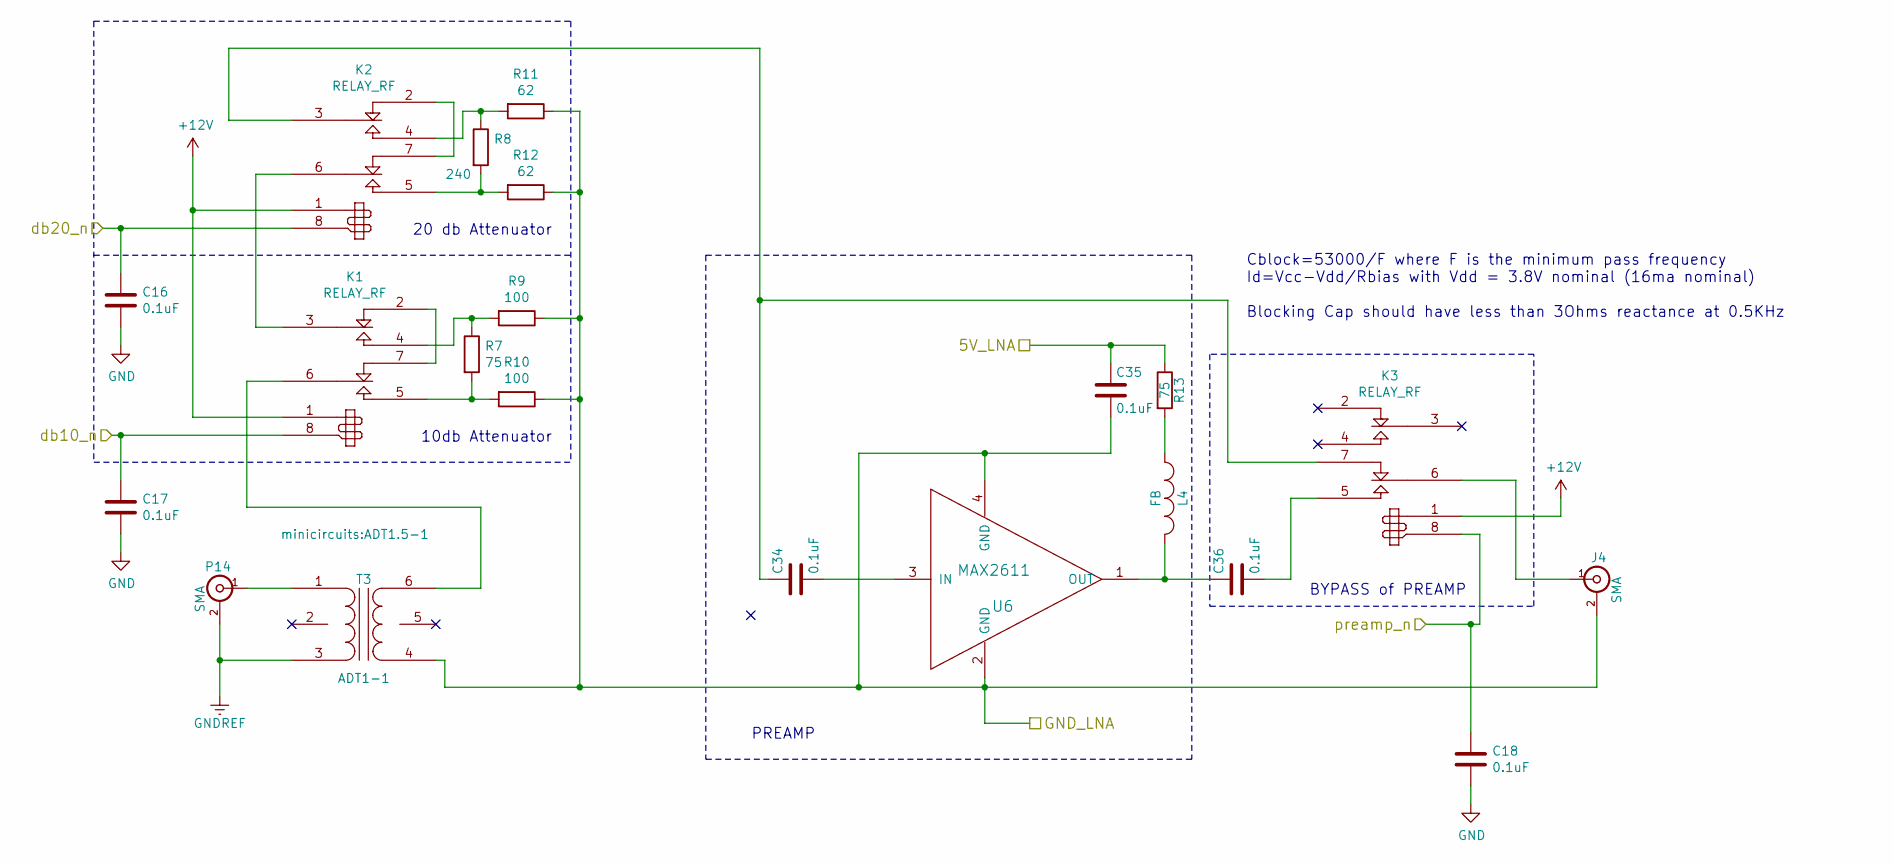
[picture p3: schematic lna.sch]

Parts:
C16, C17, C18, C34, C35, C36: 0.1uF; C_0805_2012Metric_Pad1.15x1.40mm_HandSolder
J4: SMA; SMA_Amphenol_132291-12_Vertical; Mouser Part Number 712-CONSMA001-C-G
K1, K2, K3: RELAY_RF; G6J-2P-Y
L4: FB; L_0805_2012Metric_Pad1.15x1.40mm_HandSolder
P14: SMA; SMA_Amphenol_132291-12_Vertical; Mouser Part NUmber 712-CONSMA001-C-G
R7, R13: 75; R_0805_2012Metric_Pad1.15x1.40mm_HandSolder
R8: 240; R_0805_2012Metric_Pad1.15x1.40mm_HandSolder
R9, R10: 100; R_0805_2012Metric_Pad1.15x1.40mm_HandSolder
R11, R12: 62; R_0805_2012Metric_Pad1.15x1.40mm_HandSolder
T3: ADT1-1; ADT1.5-1; Mouser Part Number 139-ADT1-1
U6: MAX2611; SOT-143; Mouser Part Number 700-MAX2611EUS+T

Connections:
+12V: K1.1 (8), K2.1 (8), K3.1 (8); also elsewhere on the board
/extern_conn/db10_n: C17.1, K1.8 (9); also elsewhere on the board
/extern_conn/db20_n: C16.1, K2.8 (9); also elsewhere on the board
/extern_conn/preamp_n: C18.1, K3.8 (9); also elsewhere on the board
/lna/5V_LNA: C35.1, R13.1; also elsewhere on the board
GND: C16.2, C17.2, C18.2, C35.2, J4.2 (Ext), R9.1, R10.1, R11.1, R12.1, T3.4 (S1), U6.2 (GND), U6.4 (GND); also elsewhere on the board
GNDREF: P14.2 (Ext), T3.3 (PR2)
unnamed: C34.1, K2.3 (C2), K3.7 (R1)
unnamed: C34.2, U6.3 (IN)
unnamed: C36.1, L4.2, U6.1 (OUT)
unnamed: C36.2, K3.5 (T1)
unnamed: J4.1 (In), K3.6 (C1)
unnamed: K1.2 (R2), K1.7 (R1)
unnamed: K1.3 (C2), K2.6 (C1)
unnamed: K1.4 (T2), R7.1, R9.2
unnamed: K1.5 (T1), R7.2, R10.2
unnamed: K1.6 (C1), T3.6 (S2)
unnamed: K2.2 (R2), K2.7 (R1)
unnamed: K2.4 (T2), R8.1, R11.2
unnamed: K2.5 (T1), R8.2, R12.2
unnamed: L4.1, R13.2
unnamed: P14.1 (In), T3.1 (PR1)

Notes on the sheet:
Cblock=53000/F where F is the minimum pass frequency Id=Vcc-Vdd/Rbias with Vdd = 3.8V nominal (16ma nominal) Blocking Cap should have less than 3Ohms reactance at 0.5KHz
10db Attenuator
20 db Attenuator
BYPASS of PREAMP
PREAMP

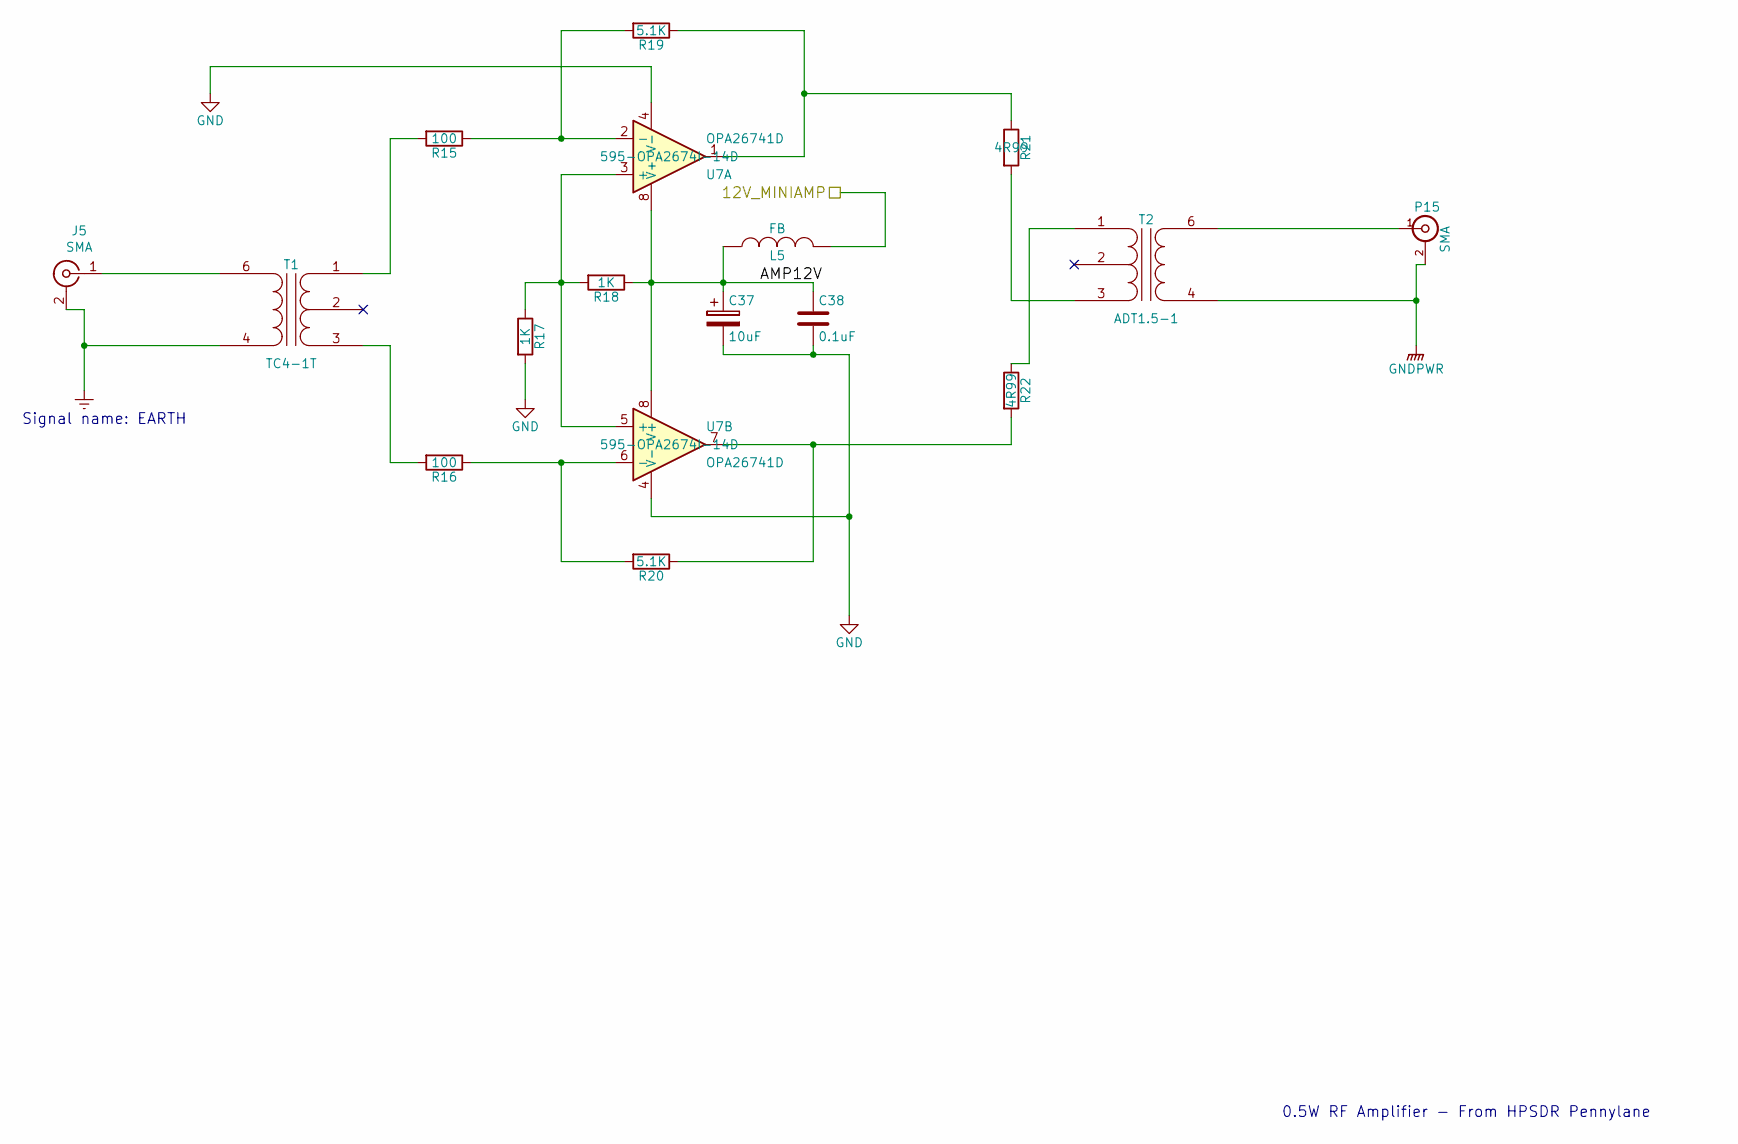
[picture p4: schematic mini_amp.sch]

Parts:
C37: 10uF; SMD-1210_Pol
C38: 0.1uF; C_0805_2012Metric_Pad1.15x1.40mm_HandSolder
J5: SMA; SMA_Amphenol_132291-12_Vertical; Mouser Part Number 712-CONSMA001-C-G
L5: FB; L_0805_2012Metric_Pad1.15x1.40mm_HandSolder
P15: SMA; SMA_Amphenol_132291-12_Vertical; Mouser Part Number 712-CONSMA001-C-G
R15, R16: 100; R_0805_2012Metric_Pad1.15x1.40mm_HandSolder
R17, R18: 1K; R_0805_2012Metric_Pad1.15x1.40mm_HandSolder
R19, R20: 5.1K; R_0805_2012Metric_Pad1.15x1.40mm_HandSolder
R21, R22: 4R99; R_0805_2012Metric_Pad1.15x1.40mm_HandSolder
T1: TC4-1T; Mouser Part Number 139-TC4-1TX
T2: ADT1.5-1; Mouser Part Number 139-ADT1.5-1
U7: OPA26741D; SOIC-8-N; Mouser Part Number 595-OPA2674I-14D

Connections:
+12V: L5.2; also elsewhere on the board
/mini_amp/AMP12V: C37.1, C38.1, L5.1, R18.1, U7.8 (V+)
Earth: J5.2 (Ext), T1.4 (S1)
GND: C37.2, C38.2, R17.2, U7.4 (V-); also elsewhere on the board
GNDPWR: P15.2 (Ext), T2.4 (S1)
unnamed: J5.1 (In), T1.6 (S2)
unnamed: P15.1 (In), T2.6 (S2)
unnamed: R15.1, R19.2, U7.2 (-)
unnamed: R15.2, T1.1 (PR1)
unnamed: R16.1, R20.2, U7.6 (-)
unnamed: R16.2, T1.3 (PR2)
unnamed: R17.1, R18.2, U7.3 (+), U7.5 (+)
unnamed: R19.1, R21.1, U7.1
unnamed: R20.1, R22.2, U7.7
unnamed: R21.2, T2.3 (PR2)
unnamed: R22.1, T2.1 (PR1)

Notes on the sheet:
0.5W RF Amplifier - From HPSDR Pennylane
Signal name: EARTH

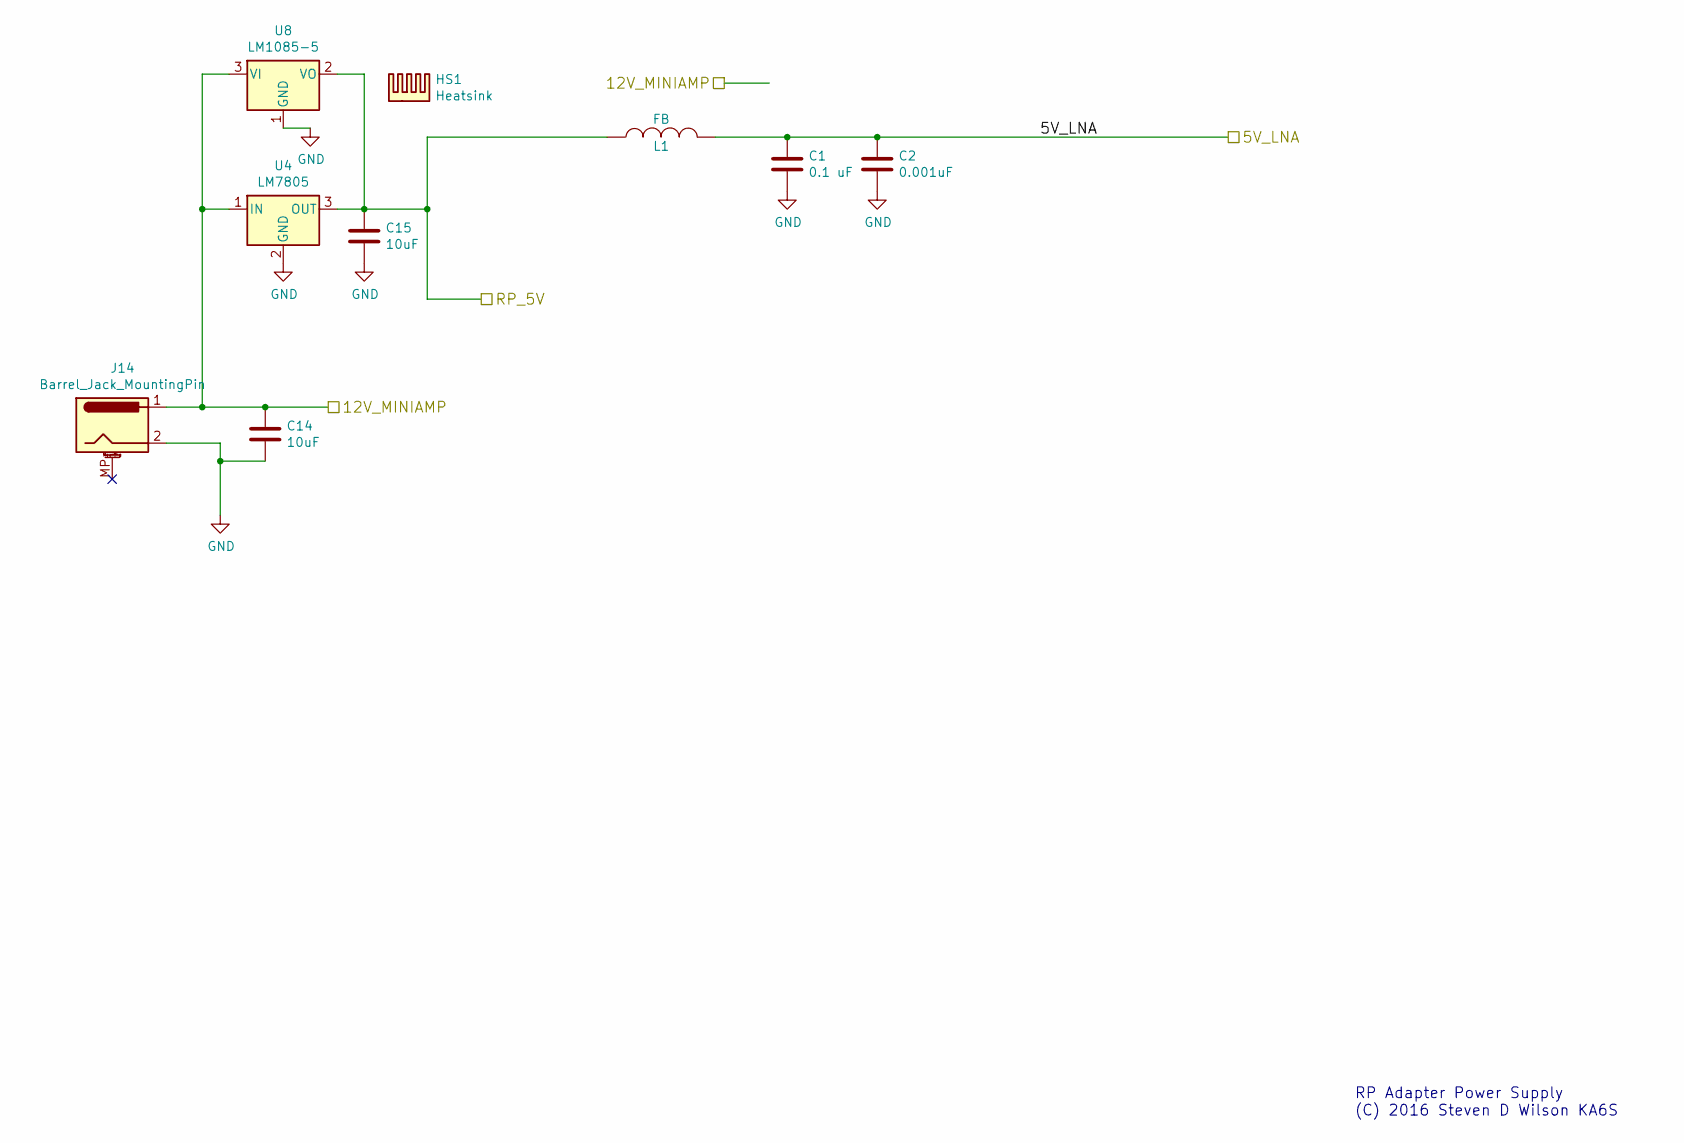
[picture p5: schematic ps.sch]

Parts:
C1: 0.1 uF; C_0805_2012Metric_Pad1.15x1.40mm_HandSolder
C2: 0.001uF; C_0805_2012Metric_Pad1.15x1.40mm_HandSolder
C14: 10uF; C_1206_3216Metric_Pad1.42x1.75mm_HandSolder; Mousr Part Number 80-C1206C106Z4VACTU
C15: 10uF; C_1206_3216Metric_Pad1.42x1.75mm_HandSolder; Mouser Part Number 80-C1206C106Z4VACTU
HS1: Heatsink; Heatsink_Fischer_SK129-STS_42x25mm_2xDrill2.5mm
J14: Barrel_Jack_MountingPin; BarrelJack_Horizontal
L1: FB; L_0805_2012Metric_Pad1.15x1.40mm_HandSolder
U4: LM7805; TO-220-3_Vertical; Mouser Part Number 511-LD1085V50
U8: LM1085-5; TO-220-3_Vertical; Mouser Part Number 511-LD1085V50

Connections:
+12V: C14.1, J14.1, U4.1 (IN), U8.3 (VI); also elsewhere on the board
/lna/5V_LNA: C1.1, C2.1, L1.2; also elsewhere on the board
/ps/RP_5V: C15.1, L1.1, U4.3 (OUT), U8.2 (VO); also elsewhere on the board
GND: C1.2, C2.2, C14.2, C15.2, J14.2, U4.2 (GND), U8.1 (GND); also elsewhere on the board

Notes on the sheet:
RP Adapter Power Supply (C) 2016 Steven D Wilson KA6S

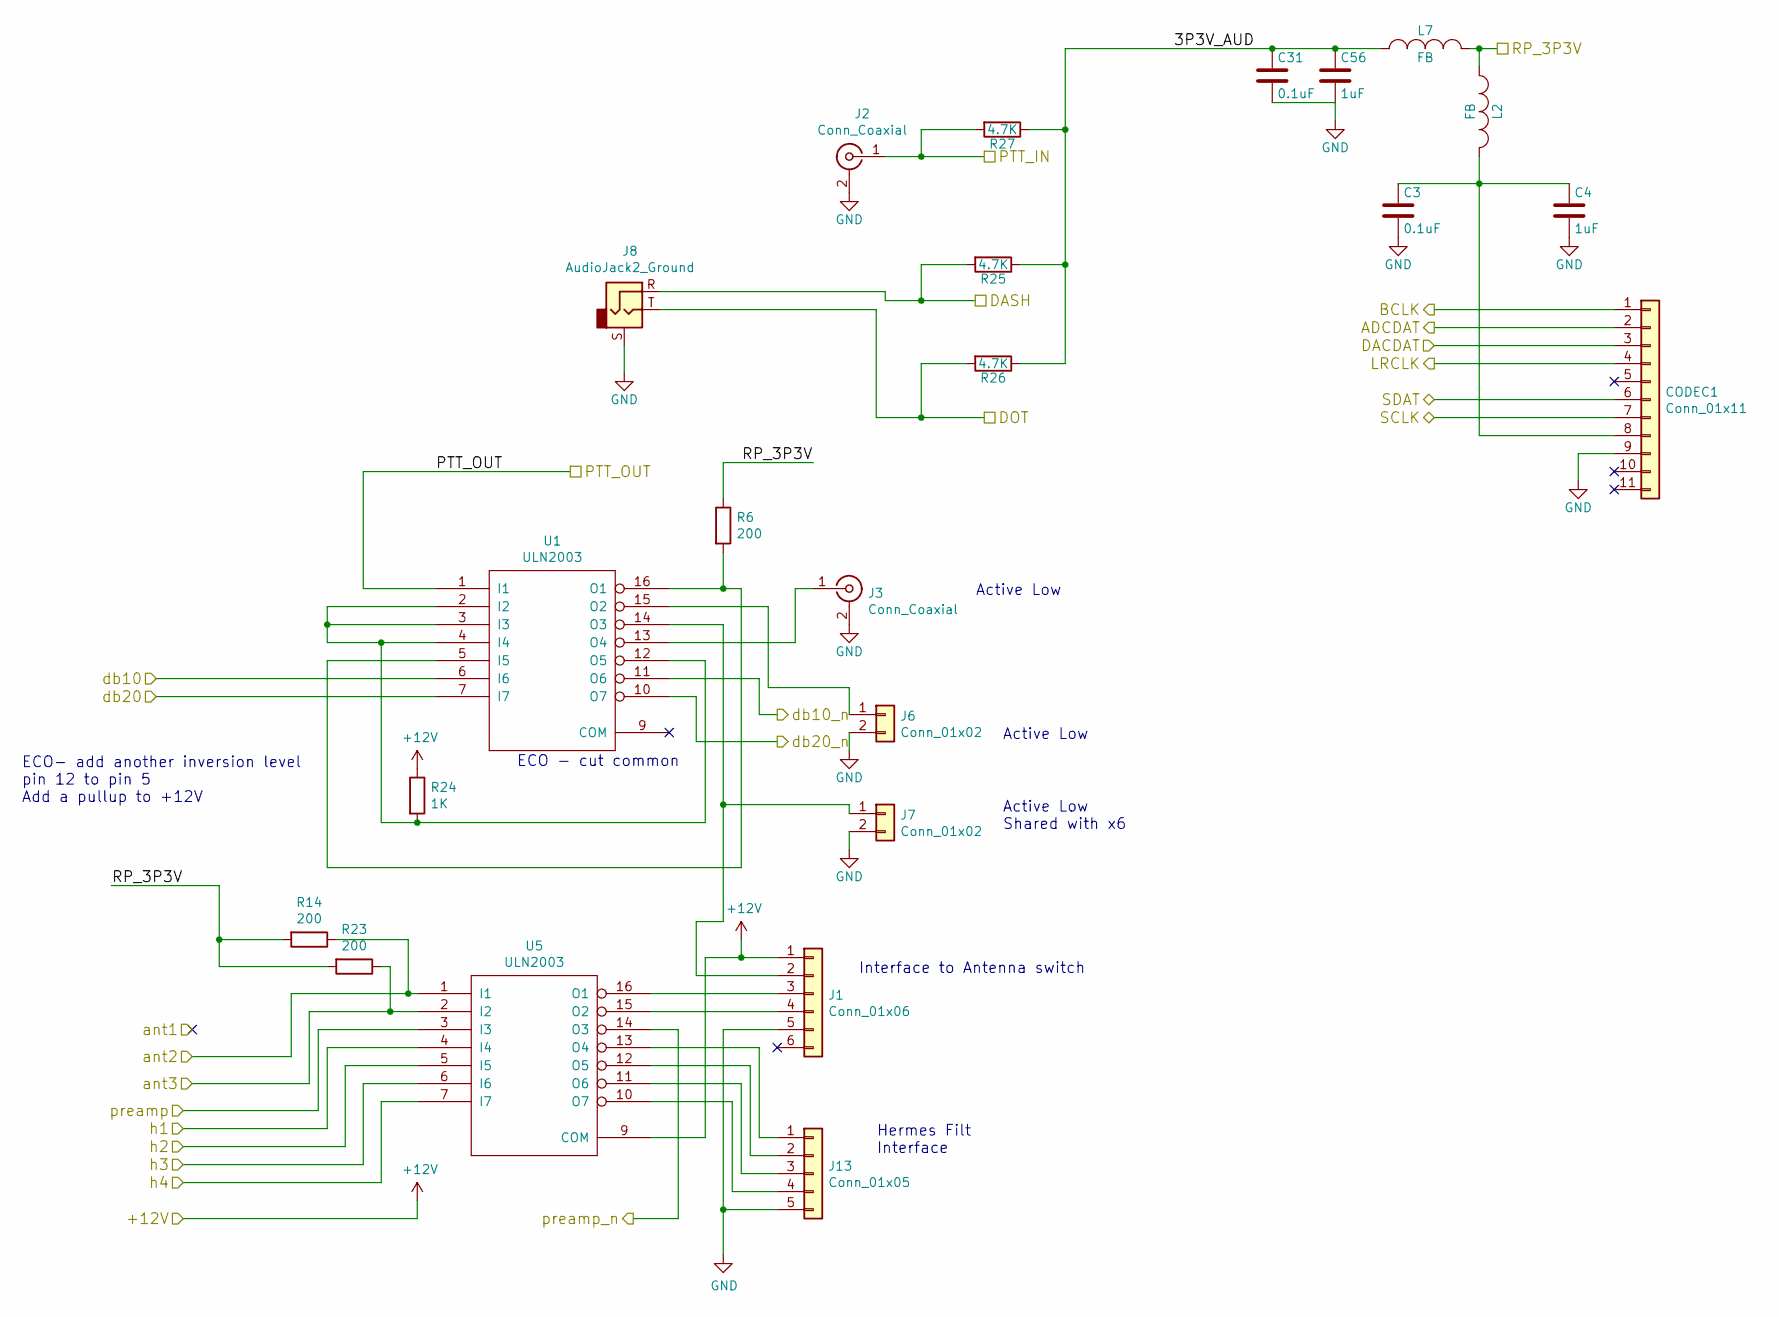
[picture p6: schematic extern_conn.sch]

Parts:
C3, C31: 0.1uF; C_0805_2012Metric_Pad1.15x1.40mm_HandSolder
C4, C56: 1uF; C_0805_2012Metric_Pad1.15x1.40mm_HandSolder
CODEC1: Conn_01x11; CODEC
J1: Conn_01x06; PinHeader_1x06_P2.54mm_Vertical
J2, J3: Conn_Coaxial; RCAVertical; Mouser Part Number 490-RCJ-027
J6, J7: Conn_01x02; PinHeader_1x02_P2.54mm_Vertical
J8: AudioJack2_Ground; Audio_3P_Vertical; Mouser Part Number 523-ACJS-MV35-3
J13: Conn_01x05; PinHeader_1x05_P2.54mm_Vertical
L2, L7: FB; L_0805_2012Metric_Pad1.15x1.40mm_HandSolder
R6, R14, R23: 200; R_0805_2012Metric_Pad1.15x1.40mm_HandSolder
R24: 1K; R_0805_2012Metric_Pad1.15x1.40mm_HandSolder
R25, R26, R27: 4.7K; R_0805_2012Metric_Pad1.15x1.40mm_HandSolder
U1, U5: ULN2003; SOIC-16_3.9x9.9mm_P1.27mm

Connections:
+12V: J1.1, R24.1, U5.9 (COM); also elsewhere on the board
/ADCDAT: CODEC1.2; also elsewhere on the board
/BCLK: CODEC1.1; also elsewhere on the board
/DACDAT: CODEC1.3; also elsewhere on the board
/I2C to SPI/RP_3.3V: L2.1, L7.2, R6.1, R14.2, R23.2; also elsewhere on the board
/I2C to SPI/ant2: R14.1, U5.1 (I1); also elsewhere on the board
/I2C to SPI/ant3: R23.1, U5.2 (I2); also elsewhere on the board
/LRCLK: CODEC1.4; also elsewhere on the board
/PTT_OUT: U1.1 (I1); also elsewhere on the board
/SCLK: CODEC1.7; also elsewhere on the board
/SDAT: CODEC1.6; also elsewhere on the board
/db10: U1.6 (I6), U1.7 (I7); also elsewhere on the board
/extern_conn/3P3V_AUD: C31.1, C56.1, L7.1, R25.1, R26.1, R27.1
/extern_conn/DASH: J8.R, R25.2; also elsewhere on the board
/extern_conn/DOT: J8.T, R26.2; also elsewhere on the board
/extern_conn/PTT_IN: J2.1 (In), R27.2; also elsewhere on the board
/extern_conn/db10_n: U1.11 (O6); also elsewhere on the board
/extern_conn/db20_n: U1.10 (O7); also elsewhere on the board
/extern_conn/preamp_n: U5.14 (O3); also elsewhere on the board
/h1: U5.4 (I4); also elsewhere on the board
/h2: U5.5 (I5); also elsewhere on the board
/h3: U5.6 (I6), U5.7 (I7); also elsewhere on the board
/preamp: U5.3 (I3); also elsewhere on the board
GND: C3.2, C4.2, C31.2, C56.2, CODEC1.9, J1.5, J2.2 (Ext), J3.2 (Ext), J6.2, J7.2, J8.S, J13.5, U1.8 (GND), U5.8 (GND); also elsewhere on the board
unnamed: C3.1, C4.1, CODEC1.8, L2.2
unnamed: J1.2, J7.1, U1.14 (O3)
unnamed: J1.3, U5.16 (O1)
unnamed: J1.4, U5.15 (O2)
unnamed: J3.1 (In), U1.13 (O4)
unnamed: J6.1, U1.15 (O2)
unnamed: J13.1, U5.13 (O4)
unnamed: J13.2, U5.12 (O5)
unnamed: J13.3, U5.11 (O6)
unnamed: J13.4, U5.10 (O7)
unnamed: R6.2, U1.5 (I5), U1.16 (O1)
unnamed: R24.2, U1.2 (I2), U1.3 (I3), U1.4 (I4), U1.12 (O5)

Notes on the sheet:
ECO - cut common
ECO- add another inversion level pin 12 to pin 5 Add a pullup to +12V
Active Low
Active Low Shared with x6
Interface to Antenna switch
Hermes Filt Interface

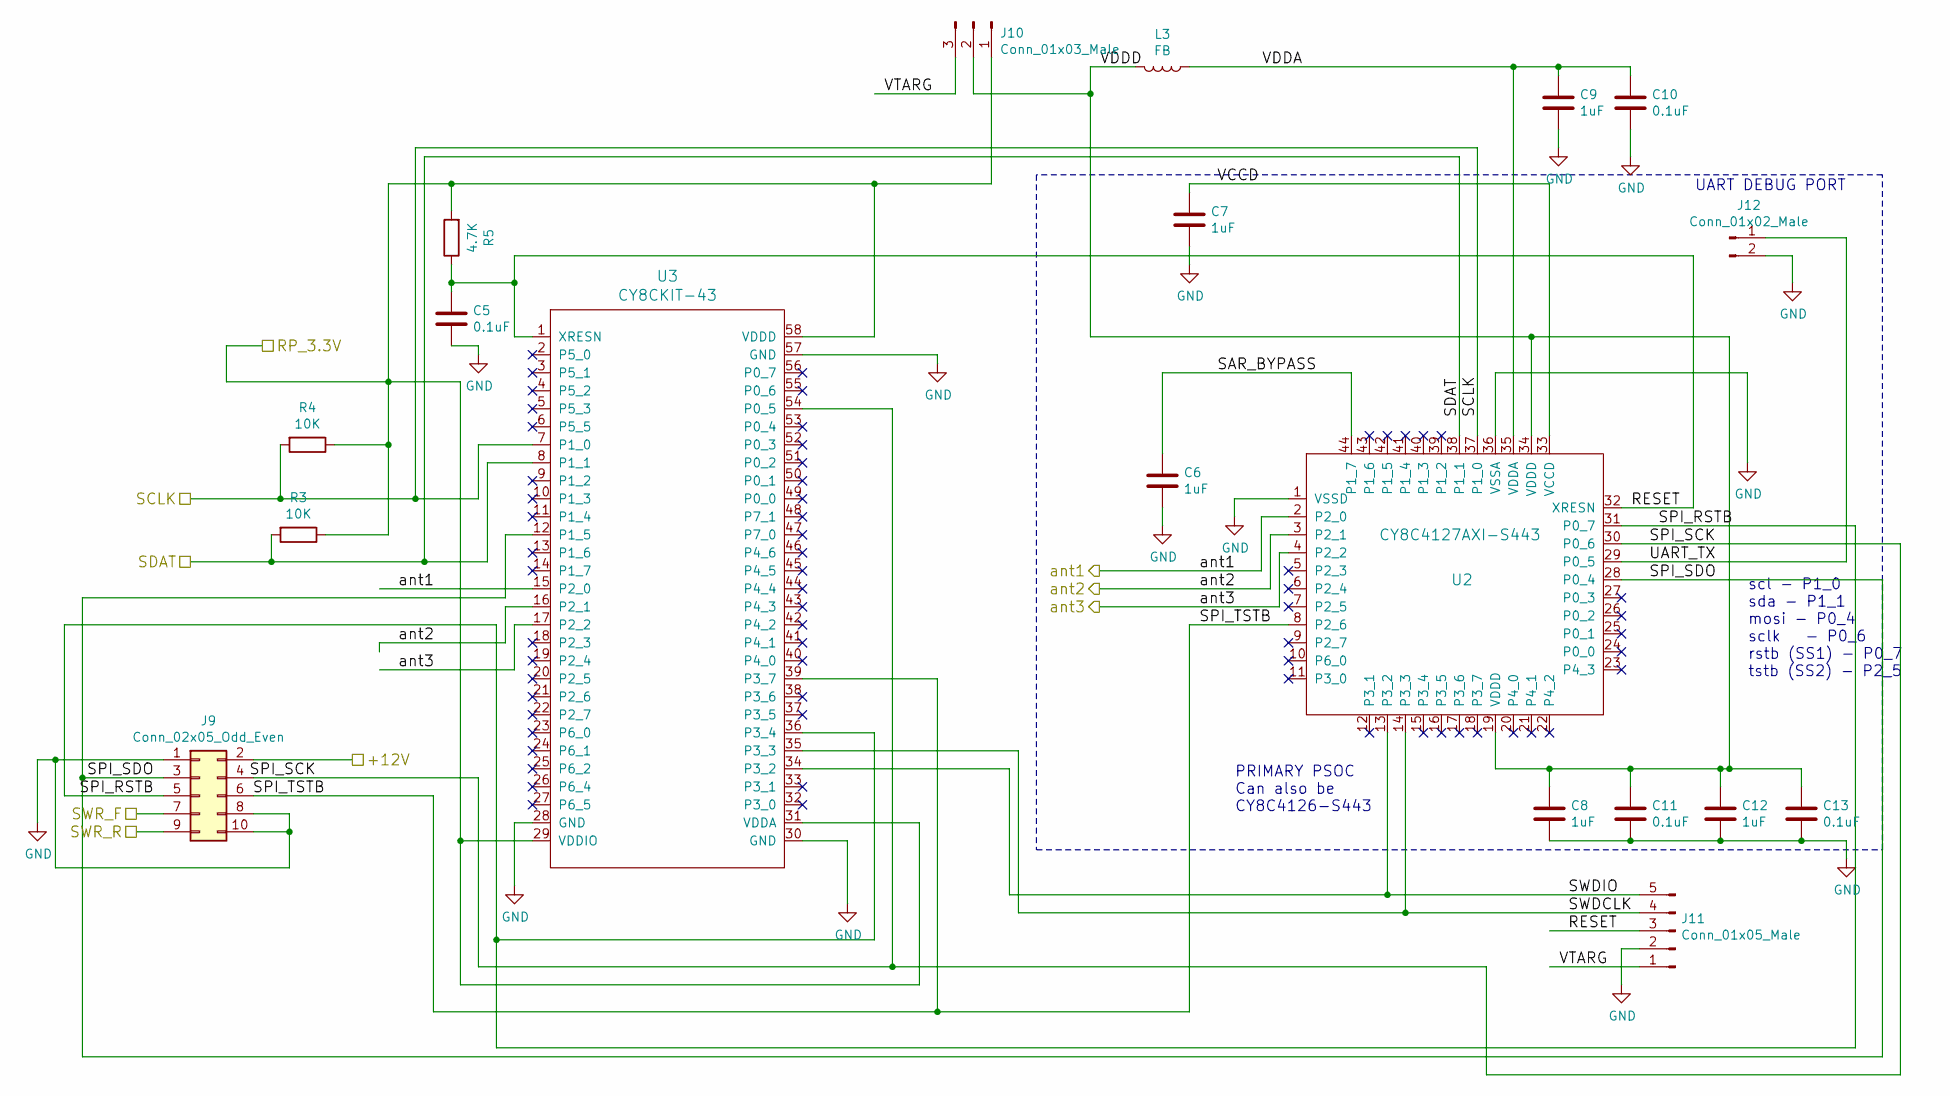
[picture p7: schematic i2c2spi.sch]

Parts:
C5, C10, C11, C13: 0.1uF; C_0805_2012Metric_Pad1.15x1.40mm_HandSolder
C6, C7, C8, C9, C12: 1uF; C_0805_2012Metric_Pad1.15x1.40mm_HandSolder
J9: Conn_02x05_Odd_Even; PinHeader_2x05_P2.54mm_Vertical
J10: Conn_01x03_Male; PinHeader_1x03_P2.54mm_Vertical
J11: Conn_01x05_Male; PinHeader_1x05_P2.54mm_Vertical
J12: Conn_01x02_Male; PinHeader_1x02_P2.54mm_Vertical
L3: FB; L_0805_2012Metric_Pad1.15x1.40mm_HandSolder
R3, R4: 10K; R_0805_2012Metric_Pad1.15x1.40mm_HandSolder
R5: 4.7K; R_0805_2012Metric_Pad1.15x1.40mm_HandSolder
U2: CY8C4127AXI-S443; TQFP-44_10x10mm_P0.8mm
U3: CY8CKIT-43

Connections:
+12V: J9.2; also elsewhere on the board
/I2C to SPI/RESET: C5.1, J11.3, R5.1, U2.32 (XRESN), U3.1 (XRESN)
/I2C to SPI/RP_3.3V: J10.1, R3.1, R4.1, R5.2, U3.29 (VDDIO), U3.31 (VDDA), U3.58 (VDDD); also elsewhere on the board
/I2C to SPI/SAR_BYPASS: C6.1, U2.44 (P1_7)
/I2C to SPI/SPI_RSTB: J9.5, U2.31 (P0_7), U3.36 (P3_4)
/I2C to SPI/SPI_SCK: J9.4, U2.30 (P0_6), U3.54 (P0_5)
/I2C to SPI/SPI_SDO: J9.3, U2.28 (P0_4), U3.12 (P1_5)
/I2C to SPI/SPI_TSTB: J9.6, U2.8 (P2_6), U3.39 (P3_7)
/I2C to SPI/SWDCLK: J11.4, U2.14 (P3_3), U3.35 (P3_3)
/I2C to SPI/SWDIO: J11.5, U2.13 (P3_2), U3.34 (P3_2)
/I2C to SPI/SWR_F: J9.7; also elsewhere on the board
/I2C to SPI/SWR_R: J9.9; also elsewhere on the board
/I2C to SPI/UART_TX: J12.1, U2.29 (P0_5)
/I2C to SPI/VCCD: C7.1, U2.33 (VCCD)
/I2C to SPI/VDDA: C9.1, C10.1, L3.1, U2.35 (VDDA)
/I2C to SPI/VDDD: C8.1, C11.1, C12.1, C13.1, J10.2, L3.2, U2.19 (VDDD), U2.34 (VDDD)
/I2C to SPI/VTARG: J10.3, J11.1
/I2C to SPI/ant1: U2.2 (P2_0), U3.15 (P2_0)
/I2C to SPI/ant2: U2.3 (P2_1), U3.16 (P2_1); also elsewhere on the board
/I2C to SPI/ant3: U2.4 (P2_2), U3.17 (P2_2); also elsewhere on the board
/SCLK: R4.2, U2.37 (P1_0), U3.7 (P1_0); also elsewhere on the board
/SDAT: R3.2, U2.38 (P1_1), U3.8 (P1_1); also elsewhere on the board
GND: C5.2, C6.2, C7.2, C8.2, C9.2, C10.2, C11.2, C12.2, C13.2, J9.1, J9.8, J9.10, J11.2, J12.2, U2.1 (VSSD), U2.36 (VSSA), U3.28 (GND), U3.30 (GND), U3.57 (GND); also elsewhere on the board

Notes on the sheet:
scl - P1_0 sda - P1_1 mosi - P0_4 sclk - P0_6 rstb (SS1) - P0_7 tstb (SS2) - P2_5
UART DEBUG PORT
PRIMARY PSOC Can also be CY8C4126-S443

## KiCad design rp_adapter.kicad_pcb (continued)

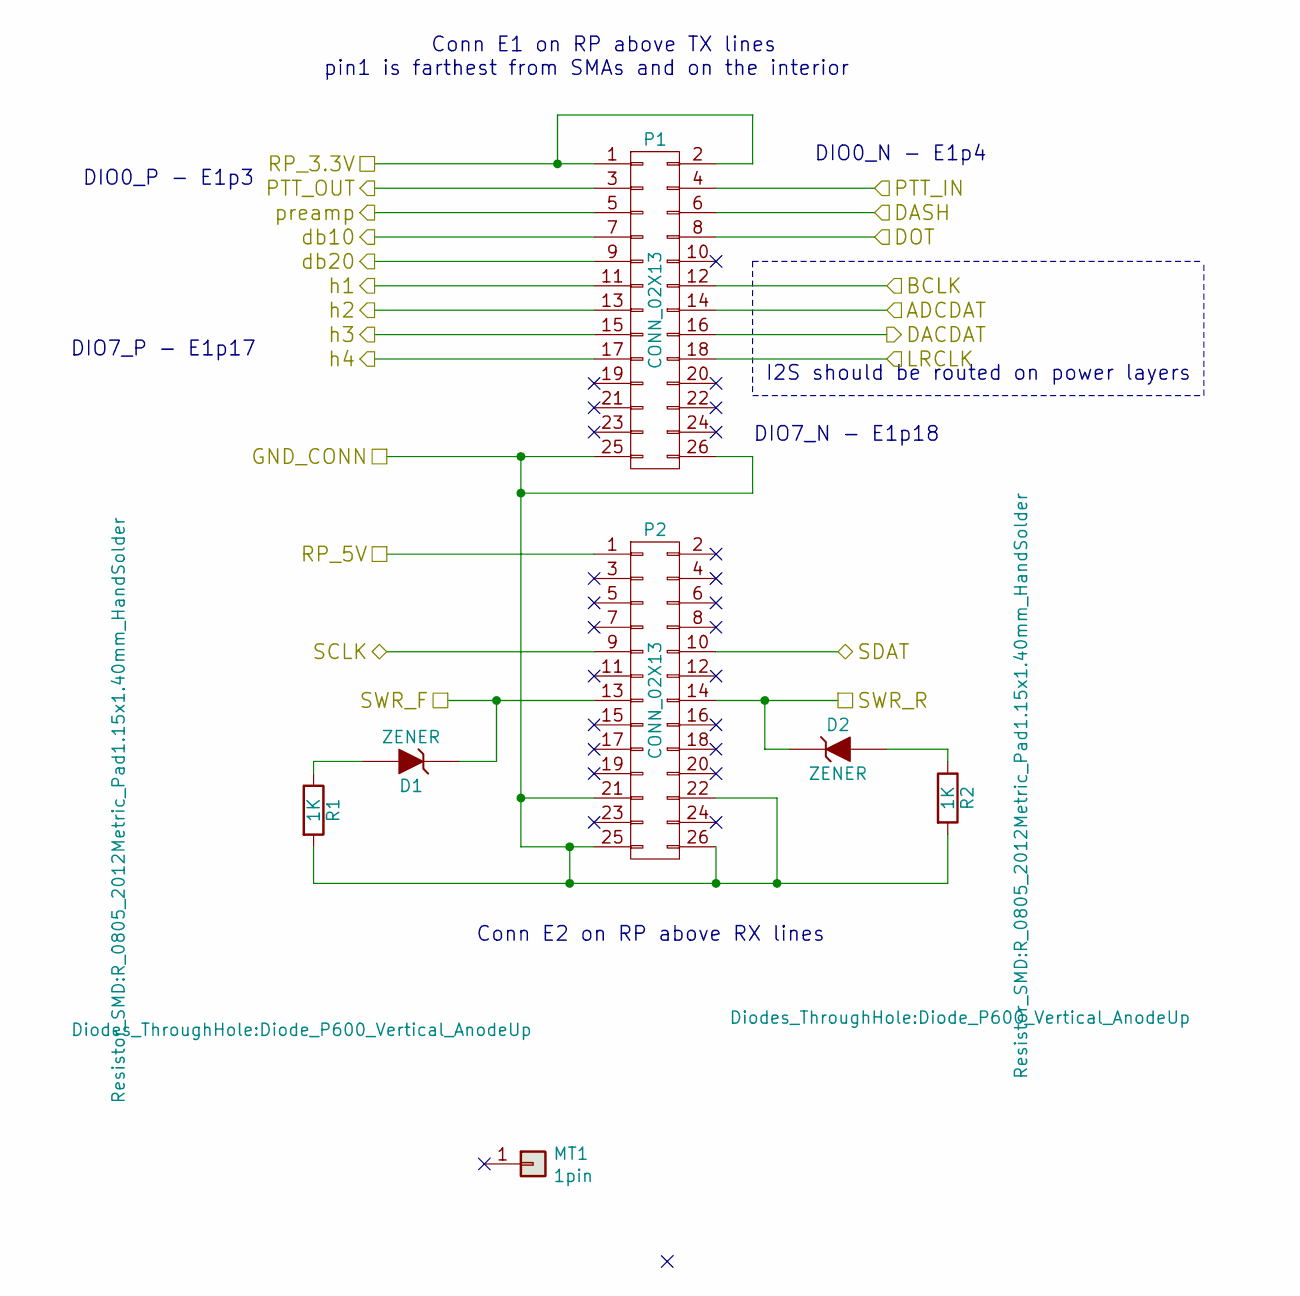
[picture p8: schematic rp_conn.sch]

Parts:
D1, D2: ZENER; Diode_P600_Vertical_AnodeUp
MT1: 1pin; 1Pin
P1, P2: CONN_02X13; Pin_Header_Straight_2x13
R1, R2: 1K; R_0805_2012Metric_Pad1.15x1.40mm_HandSolder

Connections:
/ADCDAT: P1.14; also elsewhere on the board
/BCLK: P1.12; also elsewhere on the board
/DACDAT: P1.16; also elsewhere on the board
/I2C to SPI/RP_3.3V: P1.1, P1.2; also elsewhere on the board
/I2C to SPI/SWR_F: D1.1 (K), P2.13; also elsewhere on the board
/I2C to SPI/SWR_R: D2.1 (K), P2.14; also elsewhere on the board
/LRCLK: P1.18; also elsewhere on the board
/PTT_OUT: P1.3; also elsewhere on the board
/SCLK: P2.9; also elsewhere on the board
/SDAT: P2.10; also elsewhere on the board
/db10: P1.7, P1.9; also elsewhere on the board
/extern_conn/DASH: P1.6; also elsewhere on the board
/extern_conn/DOT: P1.8; also elsewhere on the board
/extern_conn/PTT_IN: P1.4; also elsewhere on the board
/h1: P1.11; also elsewhere on the board
/h2: P1.13; also elsewhere on the board
/h3: P1.15, P1.17; also elsewhere on the board
/preamp: P1.5; also elsewhere on the board
/ps/RP_5V: P2.1; also elsewhere on the board
GND: P1.25, P1.26, P2.21, P2.22, P2.25, P2.26, R1.2, R2.2; also elsewhere on the board
unnamed: D1.2 (A), R1.1
unnamed: D2.2 (A), R2.1

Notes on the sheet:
Conn E1 on RP above TX lines
Conn E2 on RP above RX lines
pin1 is farthest from SMAs and on the interior
DIO0_P - E1p3
DIO7_P - E1p17
DIO0_N - E1p4
DIO7_N - E1p18
I2S should be routed on power layers

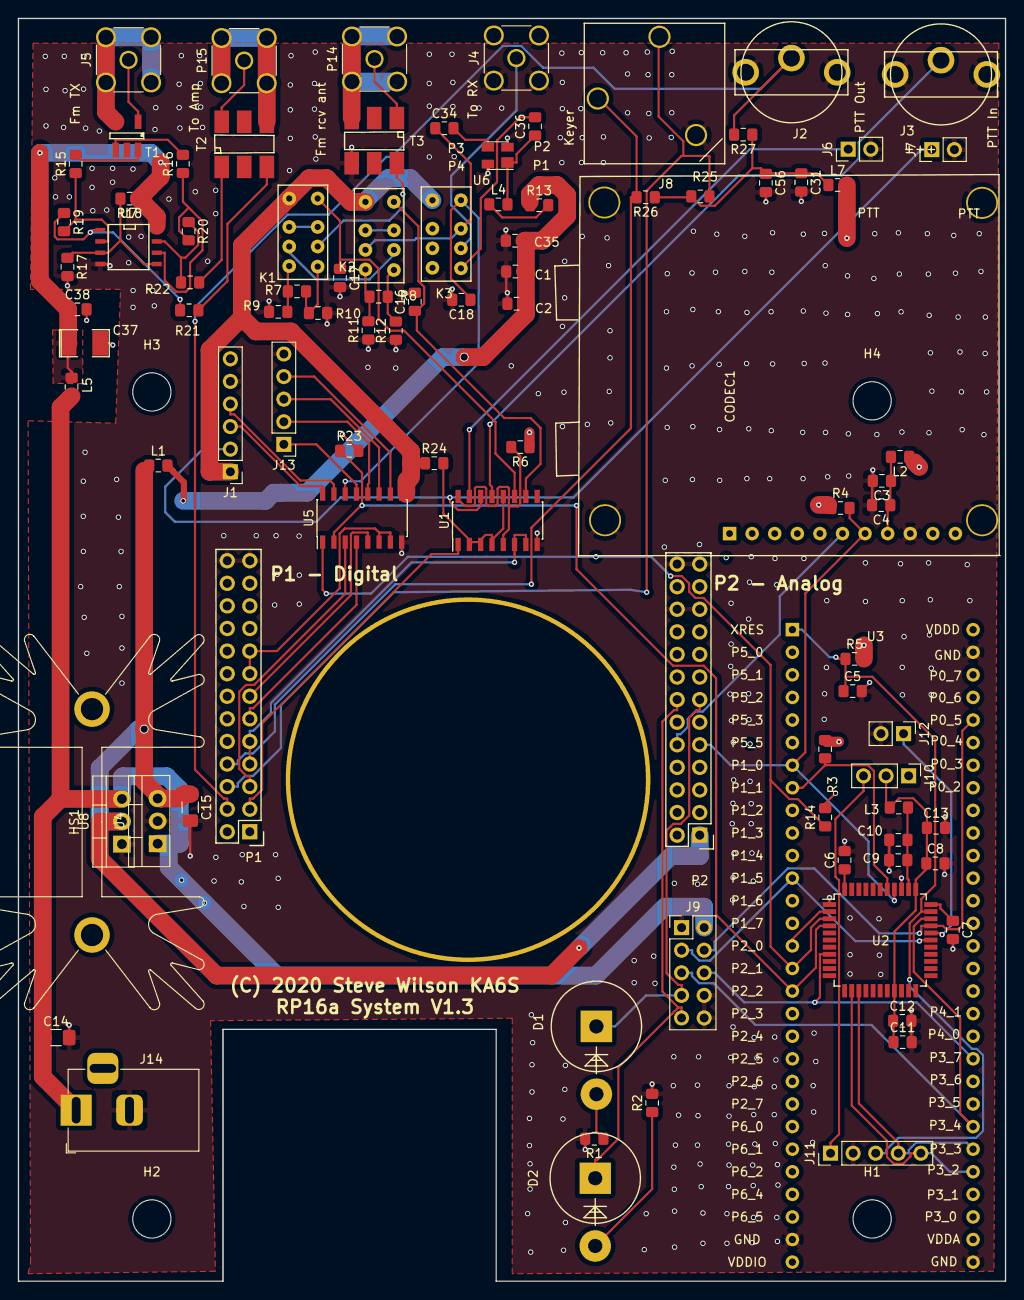
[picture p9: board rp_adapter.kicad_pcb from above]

Board: 4 copper layers, 111.0 x 142.0 mm, 99 parts (1 on the bottom side), 86 nets.

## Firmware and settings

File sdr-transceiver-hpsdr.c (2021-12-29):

/*
19.04.2016 DC2PD: add code for bandpass and antenna switching via I2C.
22.08.2016 DL4AOI: add code for TX level switching via I2C.
22.08.2016 DL4AOI: output first four open collector outputs to the pins DIO4_P - DIO7_P of the extension connector E1.
02.09.2016 ON3VNA: add code for TX level switching via DS1803-10 (I2C).
21.09.2016 DC2PD: add code for controlling AD8331 VGA with MCP4725 DAC (I2C).
02.10.2016 DL9LJ: add code for controlling ICOM IC-735 (UART).
03.12.2016 KA6S: add CW keyer code.
16.08.2017 G8NJJ: add code for controlling G8NJJ Arduino sketch (I2C).
*/

#include <stdio.h>
#include <errno.h>
#include <stdlib.h>
#include <limits.h>
#include <stdint.h>
#include <string.h>
#include <unistd.h>
#include <fcntl.h>
#include <math.h>
#include <pthread.h>
#include <termios.h>
#include <sys/mman.h>
#include <sys/time.h>
#include <sys/ioctl.h>
#include <sys/socket.h>
#include <netinet/in.h>
#include <arpa/inet.h>
#include <net/if.h>

// #define DEBUG 1
#define I2C_SLAVE       0x0703 /* Use this slave address */
#define I2C_SLAVE_FORCE 0x0706 /* Use this slave address, even if it
                                  is already in use by a driver! */

#define ADDR_PENE 0x20 /* PCA9555 address 0 */
#define ADDR_ALEX 0x21 /* PCA9555 address 1 */
#define ADDR_LEVEL 0x22 /* PCA9555 address 2 */
#define ADDR_MISC 0x23 /* PCA9555 address 3 */
#define ADDR_I2C2SPI 0x24 /* Alex I2C to SPI */
#define ADDR_DRIVE 0x28 /* DS1803 address 0 */
#define ADDR_CODEC 0x1A /* WM8731 or TLV320AIC23B address 0 */
#define ADDR_DAC0 0x60 /* MCP4725 address 0 */
#define ADDR_DAC1 0x61 /* MCP4725 address 1 */
#define ADDR_ARDUINO 0x40 /* G8NJJ Arduino sketch */
#define ADDR_NUCLEO 0x55 /* NUCLEO-G071RB */

volatile uint32_t *rx_freq[3], *tx_freq, *alex, *tx_mux, *dac_freq;
volatile uint16_t *rx_rate, *rx_cntr, *tx_cntr, *dac_cntr, *adc_cntr;
volatile int16_t *tx_level, *dac_level;
volatile uint8_t *gpio_in, *gpio_out, *rx_rst, *tx_rst, *lo_rst;
volatile uint64_t *rx_data[5];
volatile uint32_t *tx_data, *dac_data;
volatile uint16_t *adc_data;
volatile int32_t *xadc;

const uint32_t freq_min = 0;
const uint32_t freq_max = 61440000;

int receivers = 1;
int rate = 0;

int sock_ep2;
struct sockaddr_in addr_ep6;

int enable_thread = 0;
int active_thread = 0;

void process_ep2(uint8_t *frame);
void *handler_ep6(void *arg);
void *handler_keyer(void *arg);

/* variables to handle I2C devices */
int i2c_fd;
int i2c_pene = 0;
int i2c_alex = 0;
int i2c_level = 0;
int i2c_misc = 0;
int i2c_drive = 0;
int i2c_codec = 0;
int i2c_dac0 = 0;
int i2c_dac1 = 0;
int i2c_arduino = 0;
int i2c_nucleo = 0;

uint16_t i2c_pene_data = 0;
uint16_t i2c_alex_data = 0;
uint16_t i2c_level_data = 0;
uint16_t i2c_misc_data = 0;
uint16_t i2c_drive_data = 0;
uint16_t i2c_dac0_data = 0xfff;
uint16_t i2c_dac1_data = 0xfff;
uint32_t i2c_nucleo_data[2] = {0};

uint16_t i2c_ard_frx1_data = 0; /* rx 1 freq in kHz */
uint16_t i2c_ard_frx2_data = 0; /* rx 2 freq in kHz */
uint16_t i2c_ard_ftx_data = 0; /* tx freq in kHz */
uint32_t i2c_ard_ocant_data = 0; /* oc output and ant */
uint32_t i2c_ard_txatt_data = 0; /* tx attenuation and oddments  */
uint16_t i2c_ard_rxatt_data = 0; /* rx attenuation */

uint8_t log_table_lookup[256]; /* lookup table from linear scale to
                                  6 bit / 0.5 dB attenuation */

uint8_t i2c_boost_data = 0;

uint8_t dac_level_data = 0;

uint8_t cw_int_data = 0;
uint8_t rx_att_data = 0;
uint8_t tx_mux_data = 0;
uint8_t tx_eer_data = 0;

uint16_t cw_hang = 0;
uint8_t cw_reversed = 0;
uint8_t cw_speed = 25;
uint8_t cw_mode = 0;
uint8_t cw_weight = 50;
uint8_t cw_spacing = 0;
uint8_t cw_delay = 0;
uint8_t cw_ptt = 0;

int cw_memory[2] = {0, 0};
int cw_ptt_delay = 0;

uint16_t rx_sync_data = 0;

ssize_t i2c_write_addr_data8(int fd, uint8_t addr, uint8_t data)
{
  uint8_t buffer[2];
  buffer[0] = addr;
  buffer[1] = data;
  return write(fd, buffer, 2);
}

ssize_t i2c_write_addr_data16(int fd, uint8_t addr, uint16_t data)
{
  uint8_t buffer[3];
  buffer[0] = addr;
  buffer[1] = data;
  buffer[2] = data >> 8;
  return write(fd, buffer, 3);
}

ssize_t i2c_write_addr_data24(int fd, uint8_t addr, uint32_t data)
{
  uint8_t buffer[4];
  buffer[0] = addr;
  buffer[1] = data;
  buffer[2] = data >> 8;
  buffer[3] = data >> 16;
  return write(fd, buffer, 4);
}

ssize_t i2c_write_data16(int fd, uint16_t data)
{
  uint8_t buffer[2];
  buffer[0] = data >> 8;
  buffer[1] = data;
  return write(fd, buffer, 2);
}

ssize_t i2c_write_data40(int fd, uint32_t low, uint32_t high)
{
  uint32_t buffer[2];
  buffer[0] = low;
  buffer[1] = high;
  return write(fd, buffer, 5);
}

uint16_t alex_data_rx = 0;
uint16_t alex_data_tx = 0;
uint16_t alex_data_0 = 0;
uint16_t alex_data_1 = 0;
uint16_t alex_update = 0;
uint16_t i2c_2_spi = 0;

uint32_t freq_data[3] = {0, 0, 0};

/* calculate lookup table from drive scale value to 0.5 dB attenuation units */
void calc_log_lookup()
{
  int index;
  float value;
  uint8_t att;

  log_table_lookup[0] = 63; /* max att if no drive */
  for(index = 1; index < 256; ++index)
  {
    value = -40.0 * log10((float)index / 255.0);
    if(value > 63.0)
    {
      att = 63;
    }
    else
    {
      att = (uint8_t)value;
    }
    log_table_lookup[index] = att;
  }
}

void alex_write()
{
  uint32_t max = freq_data[1] > freq_data[2] ? freq_data[1] : freq_data[2];
  uint16_t manual = (alex_data_1 >> 15) & 0x01;
  uint16_t preamp = manual ? (alex_data_1 >> 6) & 0x01 : max > 50000000;
  uint16_t ptt = alex_data_0 & 0x01;
  uint32_t freq = 0;
  uint16_t hpf = 0, lpf = 0, data = 0;
  uint16_t i2c_resp=0;


  //if(i2c_codec) return;


  freq = freq_data[1] < freq_data[2] ? freq_data[1] : freq_data[2];

  if(preamp) hpf = 0;
  else if(manual) hpf = alex_data_1 & 0x3f;
  else if(freq < 1416000) hpf = 0x20; /* bypass */
  else if(freq < 6500000) hpf = 0x10; /* 1.5 MHz HPF */
  else if(freq < 9500000) hpf = 0x08; /* 6.5 MHz HPF */
  else if(freq < 13000000) hpf = 0x04; /* 9.5 MHz HPF */
  else if(freq < 20000000) hpf = 0x01; /* 13 MHz HPF */
  else hpf = 0x02; /* 20 MHz HPF */

  data =
    ptt << 15 |
    ((alex_data_0 >> 1) & 0x01) << 14 |
    ((alex_data_0 >> 2) & 0x01) << 13 |
    ((hpf >> 5) & 0x01) << 12 |
    ((alex_data_0 >> 7) & 0x01) << 11 |
    (((alex_data_0 >> 5) & 0x03) == 0x01) << 10 |
    (((alex_data_0 >> 5) & 0x03) == 0x02) << 9 |
    (((alex_data_0 >> 5) & 0x03) == 0x03) << 8 |
    ((hpf >> 2) & 0x07) << 4 |
    preamp << 3 |
    (hpf & 0x03) << 1 |
    1;

  fprintf(stderr,".");
  if(alex_data_rx != data) {
    #ifdef DEBUG

    fprintf(stderr,"RX:");
    if((data & 0x0001) > 0) { fprintf(stderr,"-Yellow-");}
    if((data & 0x0002) > 0) { fprintf(stderr,"-13MHPF-");}
    if((data & 0x0004) > 0) { fprintf(stderr,"-20MHPF-");}
    if((data & 0x0008) > 0) { fprintf(stderr,"-6MPre-");}
    if((data & 0x0010) > 0) { fprintf(stderr,"-9.5HPF-");}
    if((data & 0x0020) > 0) { fprintf(stderr,"-6.5HPF-");}
    if((data & 0x0040) > 0) { fprintf(stderr,"-1.5HPF-");}
    if((data & 0x0080) > 0) { fprintf(stderr,"-N/C-");}
    if((data & 0x0100) > 0) { fprintf(stderr,"-XVTIn-");}
    if((data & 0x0200) > 0) { fprintf(stderr,"-RX2In-");}
    if((data & 0x0400) > 0) { fprintf(stderr,"-RX1In-");}
    if((data & 0x0800) > 0) { fprintf(stderr,"-RX1Out-");}
    if((data & 0x1000) > 0) { fprintf(stderr,"-BYP-");}
    if((data & 0x2000) > 0) { fprintf(stderr,"-20db-");}
    if((data & 0x4000) > 0) { fprintf(stderr,"-10db-");}
    if((data & 0x8000) > 0) { fprintf(stderr,"-Red--");}
    fprintf(stderr,"::%4x\n",data);

  
    #endif // DEBUG
    alex_data_rx = data;
    if(i2c_2_spi == 0) {
       *alex = 1 << 16 | data;
    // KA6S
    } else {
       if((i2c_resp=ioctl(i2c_fd, I2C_SLAVE_FORCE, ADDR_I2C2SPI)) >= 0) {
          i2c_write_addr_data16(i2c_fd, 1, alex_data_rx);
       }
    // End of KA6S add
    }
  }

  freq = ptt ? freq_data[0] : max;

  if(manual) lpf = (alex_data_1 >> 8) & 0x7f;
  else if(freq > 32000000) lpf = 0x10; /* bypass */
  else if(freq > 22000000) lpf = 0x20; /* 12/10 meters */
  else if(freq > 15000000) lpf = 0x40; /* 17/15 meters */
  else if(freq > 8000000) lpf = 0x01; /* 30/20 meters */
  else if(freq > 4500000) lpf = 0x02; /* 60/40 meters */
  else if(freq > 2400000) lpf = 0x04; /* 80 meters */
  else lpf = 0x08; /* 160 meters */

  data =
    ((lpf >> 4) & 0x07) << 13 |
    ptt << 12 |
    (~(alex_data_1 >> 7) & ptt) << 11 |
    (((alex_data_0 >> 8) & 0x03) == 0x02) << 10 |
    (((alex_data_0 >> 8) & 0x03) == 0x01) << 9 |
    (((alex_data_0 >> 8) & 0x03) == 0x00) << 8 |
    (lpf & 0x0f) << 4 |
    1 << 3;

  if(alex_data_tx != data)
  {
    #ifdef DEBUG
    fprintf(stderr,"TX:");
    if((data &0x0001) > 0) { fprintf(stderr,"-N/C-");}
    if((data &0x0002) > 0) { fprintf(stderr,"-N/C-");}
    if((data &0x0004) > 0) { fprintf(stderr,"-N/C-");}
    if((data &0x0008) > 0) { fprintf(stderr,"-Yellow-");}
    if((data &0x0010) > 0) { fprintf(stderr,"-30/20MF-");}
    if((data &0x0020) > 0) { fprintf(stderr,"-60/40M-");}
    if((data &0x0040) > 0) { fprintf(stderr,"-80M-");}
    if((data &0x0080) > 0) { fprintf(stderr,"-160M-");}
    if((data &0x0100) > 0) { fprintf(stderr,"-ANT1-");}
    if((data &0x0200) > 0) { fprintf(stderr,"-ANT2-");}
    if((data &0x0400) > 0) { fprintf(stderr,"-ANT3-");}
    if((data &0x0800) > 0) { fprintf(stderr,"-T/R-");}
    if((data &0x1000) > 0) { fprintf(stderr,"-RED-");}
    if((data &0x2000) > 0) { fprintf(stderr,"-6MBYPb-");}
    if((data &0x4000) > 0) { fprintf(stderr,"-12/10M-");}
    if((data &0x8000) > 0) { fprintf(stderr,"-17/15M--");}
    fprintf(stderr,"::%4x\n",data);


    #endif
    // KA6S system add
    if(i2c_2_spi == 1) {
      if((i2c_resp=ioctl(i2c_fd, I2C_SLAVE_FORCE, ADDR_I2C2SPI)) >= 0) {
         i2c_write_addr_data16(i2c_fd, 2, data);
      }
      alex_data_tx = data;
    } else {
       // End of KA6S add
       alex_data_tx = data;
       *alex = 1 << 17 | data;
    }
  }
}

static inline int lower_bound(int *array, int size, int value)
{
  int i = 0, j = size, k;
  while(i < j)
  {
    k = i + (j - i) / 2;
    if(value > array[k]) i = k + 1;
    else j = k;
  }
  return i;
}

uint16_t misc_data_0 = 0;
uint16_t misc_data_1 = 0;
uint16_t misc_data_2 = 0;
uint16_t misc_update = 0;

void misc_write()
{
  uint16_t code[3], data = 0;
  int i, freqs[20] =
  {
     1700000,  2100000,
     3400000,  3900000,
     6900000,  7350000,
     9900000, 10250000,
    13900000, 14450000,
    17950000, 18250000,
    20900000, 21550000,
    24800000, 25100000,
    26900000, 30000000,
    49000000, 55000000
  };

  for(i = 0; i < 3; ++i)
  {
    code[i] = lower_bound(freqs, 20, freq_data[i]);
    code[i] = code[i] % 2 ? code[i] / 2 + 1 : 0;
  }

  data |= (code[0] != code[1]) << 8 | code[2] << 4 | code[1];
  data |= (misc_data_1 & 0x18) << 8 | (misc_data_0 & 0x18) << 6;
  data |= (misc_data_2 & 0x03) << 13;

  if(i2c_misc_data != data)
  {
    i2c_misc_data = data;
    ioctl(i2c_fd, I2C_SLAVE, ADDR_MISC);
    i2c_write_addr_data16(i2c_fd, 0x02, data);
  }
}

uint32_t nucleo_data_0 = 0;
uint32_t nucleo_data_1 = 0;
uint32_t nucleo_data_2 = 0;
uint32_t nucleo_data_3 = 0;
uint32_t nucleo_update = 0;

void nucleo_write()
{
  uint32_t data[2] = {0};
  uint32_t code[3];
  int i, freqs[22] =
  {
     1700000,  2100000,
     3400000,  3900000,
     5250000,  5450000,
     6900000,  7350000,
     9900000, 10250000,
    13900000, 14450000,
    17950000, 18250000,
    20900000, 21550000,
    24800000, 25100000,
    26900000, 30000000,
    49000000, 55000000
  };

  for(i = 0; i < 3; ++i)
  {
    code[i] = lower_bound(freqs, 22, freq_data[i]);
    code[i] = code[i] % 2 ? code[i] / 2 + 1 : 0;
  }

  data[0] = nucleo_data_3 << 25 | nucleo_data_2 << 20 | nucleo_data_1 << 17 | nucleo_data_0 << 1 | cw_ptt << 1 | (code[0] != code[1]);
  data[1] = code[2] << 4 | code[1];

  if(i2c_nucleo_data[0] != data[0] || i2c_nucleo_data[1] != data[1])
  {
    i2c_nucleo_data[0] = data[0];
    i2c_nucleo_data[1] = data[1];
    ioctl(i2c_fd, I2C_SLAVE, ADDR_NUCLEO);
    i2c_write_data40(i2c_fd, data[0], data[1]);
  }
}

int uart_fd;
uint8_t icom_band_data = 0;

void icom_write()
{
  uint32_t freq = freq_data[0];
  uint8_t band;
  uint8_t buffer[10] = {0xfe, 0xfe, 0x04, 0xe0, 0x05, 0x00, 0x00, 0x08, 0x01, 0xfd};

  if(freq < 2000000) band = 0x01;       /* 160m */
  else if(freq < 4000000) band = 0x03;  /*  80m */
  else if(freq < 8000000) band = 0x07;  /*  40m */
  else if(freq < 11000000) band = 0x10; /*  30m */
  else if(freq < 15000000) band = 0x14; /*  20m */
  else if(freq < 20000000) band = 0x18; /*  17m */
  else if(freq < 22000000) band = 0x21; /*  15m */
  else if(freq < 26000000) band = 0x24; /*  12m */
  else band = 0x28;                     /*  10m */

  switch(band)
  {
    case 0x01:
      buffer[7] = 0x80;
      break;
    case 0x03:
      buffer[7] = 0x50;
      break;
    default:
      buffer[7] = 0x00;
  }

  buffer[8] = band;

  if(icom_band_data != band)
  {
    icom_band_data = band;
    if(uart_fd >= 0) write(uart_fd, buffer, 10);
  }
}

int main(int argc, char *argv[])
{
  int fd, i, j, size;
  struct sched_param param;
  pthread_attr_t attr;
  pthread_t thread;
  volatile void *cfg, *sts;
  volatile int32_t *tx_ramp, *dac_ramp;
  volatile uint16_t *tx_size, *dac_size;
  volatile int16_t *ps_level;
  volatile uint8_t *rx_sel, *tx_sel;
  float scale, ramp[1024], a[4] = {0.35875, 0.48829, 0.14128, 0.01168};
  uint8_t reply[11] = {0xef, 0xfe, 2, 0, 0, 0, 0, 0, 0, 32, 1};
  uint8_t id[4] = {0xef, 0xfe, 1, 6};
  uint32_t code;
  uint16_t data;
  struct termios tty;
  struct ifreq hwaddr;
  struct sockaddr_in addr_ep2, addr_from[10];
  uint8_t buffer[8][1032];
  struct iovec iovec[8][1];
  struct mmsghdr datagram[8];
  struct timeval tv;
  struct timespec ts;
  int yes = 1;
  char *end;
  uint8_t chan = 0;
  long number;

#ifdef DEBUG         
fprintf(stderr,"Starting Main\n");
#endif

  for(i = 0; i < 5; ++i)
  {
    errno = 0;
    number = (argc == 7) ? strtol(argv[i + 1], &end, 10) : -1;
    if(errno != 0 || end == argv[i + 1] || number < 1 || number > 2)
    {
      printf("Usage: sdr-transceiver-hpsdr 1|2 1|2 1|2 1|2 1|2 1|2\n");
      return EXIT_FAILURE;
    }
    chan |= (number - 1) << i;
  }

  if((fd = open("/dev/mem", O_RDWR)) < 0)
  {
    perror("open");
    return EXIT_FAILURE;
  }

  if((uart_fd = open("/dev/ttyPS1", O_RDWR | O_NOCTTY | O_NDELAY)) >= 0)
  {
    tcgetattr(uart_fd, &tty);
    cfsetspeed(&tty, (speed_t)B1200);
    cfmakeraw(&tty);
    tty.c_cflag &= ~(CSTOPB | CRTSCTS);
    tty.c_cflag |= CLOCAL | CREAD;
    tcflush(uart_fd, TCIFLUSH);
    tcsetattr(uart_fd, TCSANOW, &tty);
  }

  if((i2c_fd = open("/dev/i2c-0", O_RDWR)) >= 0)
  {
    if(ioctl(i2c_fd, I2C_SLAVE_FORCE, ADDR_PENE) >= 0)
    {
      /* set all pins to low */
      if(i2c_write_addr_data16(i2c_fd, 0x02, 0x0000) > 0)
      {
        #ifdef DEBUG         
        fprintf(stderr,"Addr PENE\n");
        #endif
        i2c_pene = 1;
        /* configure all pins as output */
        i2c_write_addr_data16(i2c_fd, 0x06, 0x0000);
      }
    }
    if(ioctl(i2c_fd, I2C_SLAVE, ADDR_ALEX) >= 0)
    {
      /* set all pins to low */
      if(i2c_write_addr_data16(i2c_fd, 0x02, 0x0000) > 0)
      {
        #ifdef DEBUG         
        fprintf(stderr,"Addr ALEX\n");
        #endif
        i2c_alex = 1;
        /* configure all pins as output */
        i2c_write_addr_data16(i2c_fd, 0x06, 0x0000);
      }
    }

    // Detect KA6S system - set i2c_alexrx/i2c_alextx if valid
    if(ioctl(i2c_fd, I2C_SLAVE_FORCE, ADDR_I2C2SPI) >= 0) {
      if(i2c_write_addr_data16(i2c_fd, 0x01, 0x0) > 0) {
         #ifdef DEBUG         
         fprintf(stderr,"I2C2SPI\n");
         #endif
         i2c_2_spi = 1;
      }
    }

    if(ioctl(i2c_fd, I2C_SLAVE, ADDR_LEVEL) >= 0)
    {
      /* set all pins to low */
      if(i2c_write_addr_data16(i2c_fd, 0x02, 0x0000) > 0)
      {
        #ifdef DEBUG         
        fprintf(stderr,"ADDR LEVEL\n");
        #endif
        i2c_level = 1;
        /* configure all pins as output */
        i2c_write_addr_data16(i2c_fd, 0x06, 0x0000);
      }
    }
    if(ioctl(i2c_fd, I2C_SLAVE, ADDR_MISC) >= 0)
    {
      /* set all pins to low */
      if(i2c_write_addr_data16(i2c_fd, 0x02, 0x0000) > 0)
      {
        #ifdef DEBUG         
        fprintf(stderr,"ADDR MISC\n");
        #endif
        i2c_misc = 1;
        /* configure all pins as output */
        i2c_write_addr_data16(i2c_fd, 0x06, 0x0000);
      }
    }
    if(ioctl(i2c_fd, I2C_SLAVE, ADDR_DRIVE) >= 0)
    {
      /* set both potentiometers to 0 */
      if(i2c_write_addr_data16(i2c_fd, 0xa9, 0x0000) > 0)
      {
        #ifdef DEBUG         
        fprintf(stderr,"ADDR DRIVE\n");
        #endif
        i2c_drive = 1;
      }
    }
    if(ioctl(i2c_fd, I2C_SLAVE, ADDR_DAC0) >= 0)
    {
      if(i2c_write_data16(i2c_fd, i2c_dac0_data) > 0)
      {
        #ifdef DEBUG         
        fprintf(stderr,"ADDR DAC0\n");
        #endif
        i2c_dac0 = 1;
      }
    }
    if(ioctl(i2c_fd, I2C_SLAVE, ADDR_DAC1) >= 0)
    {
      if(i2c_write_data16(i2c_fd, i2c_dac1_data) > 0)
      {
        #ifdef DEBUG         
        fprintf(stderr,"ADDR DAC1\n");
        #endif
        i2c_dac1 = 1;
      }
    }
    if(ioctl(i2c_fd, I2C_SLAVE, ADDR_ARDUINO) >= 0)
    {
      if(i2c_write_addr_data16(i2c_fd, 0x1, i2c_ard_frx1_data) > 0)
      {
        #ifdef DEBUG         
        fprintf(stderr,"ADDR ARDUINO\n");
        #endif
        i2c_arduino = 1;
      }
    }
    if(ioctl(i2c_fd, I2C_SLAVE, ADDR_NUCLEO) >= 0)
    {
      if(i2c_write_data40(i2c_fd, 0x02100000, 0) > 0)
      {
        #ifdef DEBUG         
        fprintf(stderr,"ADDR NUCLEO\n");
        #endif
        i2c_nucleo = 1;
      }
    }
    if(ioctl(i2c_fd, I2C_SLAVE, ADDR_CODEC) >= 0)
    {
      /* reset */
      #ifdef DEBUG         
      fprintf(stderr,"ADDR CODEC\n");
      #endif
      if(i2c_write_addr_data8(i2c_fd, 0x1e, 0x00) > 0)
      {
        i2c_codec = 1;
        /* set power down register */
        i2c_write_addr_data8(i2c_fd, 0x0c, 0x51);
        /* reset activate register */
        i2c_write_addr_data8(i2c_fd, 0x12, 0x00);
        /* set volume to -10 dB */
        i2c_write_addr_data8(i2c_fd, 0x04, 0x6f);
        i2c_write_addr_data8(i2c_fd, 0x06, 0x6f);
        /* set analog audio path register */
        i2c_write_addr_data8(i2c_fd, 0x08, 0x14);
        /* set digital audio path register */
        i2c_write_addr_data8(i2c_fd, 0x0a, 0x00);
        /* set format register */
        i2c_write_addr_data8(i2c_fd, 0x0e, 0x42);
        /* set activate register */
        i2c_write_addr_data8(i2c_fd, 0x12, 0x01);
        /* set power down register */
        i2c_write_addr_data8(i2c_fd, 0x0c, 0x41);
      }
    }
  }

  sts = mmap(NULL, sysconf(_SC_PAGESIZE), PROT_READ|PROT_WRITE, MAP_SHARED, fd, 0x40000000);
  cfg = mmap(NULL, sysconf(_SC_PAGESIZE), PROT_READ|PROT_WRITE, MAP_SHARED, fd, 0x40001000);
  alex = mmap(NULL, sysconf(_SC_PAGESIZE), PROT_READ|PROT_WRITE, MAP_SHARED, fd, 0x40002000);
  tx_mux = mmap(NULL, sysconf(_SC_PAGESIZE), PROT_READ|PROT_WRITE, MAP_SHARED, fd, 0x40003000);
  tx_ramp = mmap(NULL, sysconf(_SC_PAGESIZE), PROT_READ|PROT_WRITE, MAP_SHARED, fd, 0x40004000);
  dac_ramp = mmap(NULL, sysconf(_SC_PAGESIZE), PROT_READ|PROT_WRITE, MAP_SHARED, fd, 0x40005000);
  dac_data = mmap(NULL, sysconf(_SC_PAGESIZE), PROT_READ|PROT_WRITE, MAP_SHARED, fd, 0x40006000);
  adc_data = mmap(NULL, sysconf(_SC_PAGESIZE), PROT_READ|PROT_WRITE, MAP_SHARED, fd, 0x40007000);
  tx_data = mmap(NULL, 4*sysconf(_SC_PAGESIZE), PROT_READ|PROT_WRITE, MAP_SHARED, fd, 0x4000c000);
  xadc = mmap(NULL, 16*sysconf(_SC_PAGESIZE), PROT_READ|PROT_WRITE, MAP_SHARED, fd, 0x40020000);

  for(i = 0; i < 5; ++i)
  {
    rx_data[i] = mmap(NULL, 2*sysconf(_SC_PAGESIZE), PROT_READ|PROT_WRITE, MAP_SHARED, fd, 0x40010000 + i * 0x2000);
  }

  rx_rst = ((uint8_t *)(cfg + 0));
  lo_rst = ((uint8_t *)(cfg + 1));
  tx_rst = ((uint8_t *)(cfg + 2));
  gpio_out = ((uint8_t *)(cfg + 3));

  rx_rate = ((uint16_t *)(cfg + 4));

  rx_sel = ((uint8_t *)(cfg + 6));

  rx_freq[0] = ((uint32_t *)(cfg + 8));
  rx_freq[1] = ((uint32_t *)(cfg + 12));
  rx_freq[2] = ((uint32_t *)(cfg + 16));

  tx_freq = ((uint32_t *)(cfg + 20));
  tx_size = ((uint16_t *)(cfg + 24));
  tx_level = ((int16_t *)(cfg + 26));
  ps_level = ((int16_t *)(cfg + 28));

  tx_sel = ((uint8_t *)(cfg + 30));

  dac_freq = ((uint32_t *)(cfg + 32));
  dac_size = ((uint16_t *)(cfg + 36));
  dac_level = ((int16_t *)(cfg + 38));

  rx_cntr = ((uint16_t *)(sts + 12));
  tx_cntr = ((uint16_t *)(sts + 14));
  dac_cntr = ((uint16_t *)(sts + 16));
  adc_cntr = ((uint16_t *)(sts + 18));
  gpio_in = ((uint8_t *)(sts + 20));

  /* set rx and tx selectors */
  *rx_sel = chan & 15;
  *tx_sel = (chan >> 4) & 3;

  /* set all GPIO pins to low */
  *gpio_out = 0;

  /* set default rx phase increment */
  *rx_freq[0] = (uint32_t)floor(600000 / 122.88e6 * (1 << 30) + 0.5);
  *rx_freq[1] = (uint32_t)floor(600000 / 122.88e6 * (1 << 30) + 0.5);
  *rx_freq[2] = (uint32_t)floor(600000 / 122.88e6 * (1 << 30) + 0.5);

  /* set default rx sample rate */
  *rx_rate = 1280;

  /* set default tx phase increment */
  *tx_freq = (uint32_t)floor(600000 / 122.88e6 * (1 << 30) + 0.5);

  /* set tx ramp */
  size = 1001;
  ramp[0] = 0.0;
  for(i = 1; i <= size; ++i)
  {
    ramp[i] = ramp[i - 1] + a[0] - a[1] * cos(2.0 * M_PI * i / size) + a[2] * cos(4.0 * M_PI * i / size) - a[3] * cos(6.0 * M_PI * i / size);
  }
  scale = 4.1e6 / ramp[size];
  for(i = 0; i <= size; ++i)
  {
    tx_ramp[i] = (int32_t)floor(ramp[i] * scale + 0.5);
  }
  *tx_size = size;

  /* set default tx level */
  *tx_level = 21910;

  /* set ps level */
  *ps_level = 18716;

  /* set default tx mux channel */
  tx_mux[16] = 0;
  tx_mux[0] = 2;

  /* reset tx and codec DAC fifo */
  *tx_rst |= 3;
  *tx_rst &= ~3;

  /* reset tx lo */
  *lo_rst &= ~4;
  *lo_rst |= 4;
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

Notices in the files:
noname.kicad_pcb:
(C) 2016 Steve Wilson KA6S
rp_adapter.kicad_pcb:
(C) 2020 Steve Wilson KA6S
